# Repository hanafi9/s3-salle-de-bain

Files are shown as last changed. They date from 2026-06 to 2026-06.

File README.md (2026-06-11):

# S3 Salle de Bain

> Assistant vocal embarque ESP32-S3, prive et fonctionnant en local, dans un boitier imprime 3D dessine pour la salle de bain.






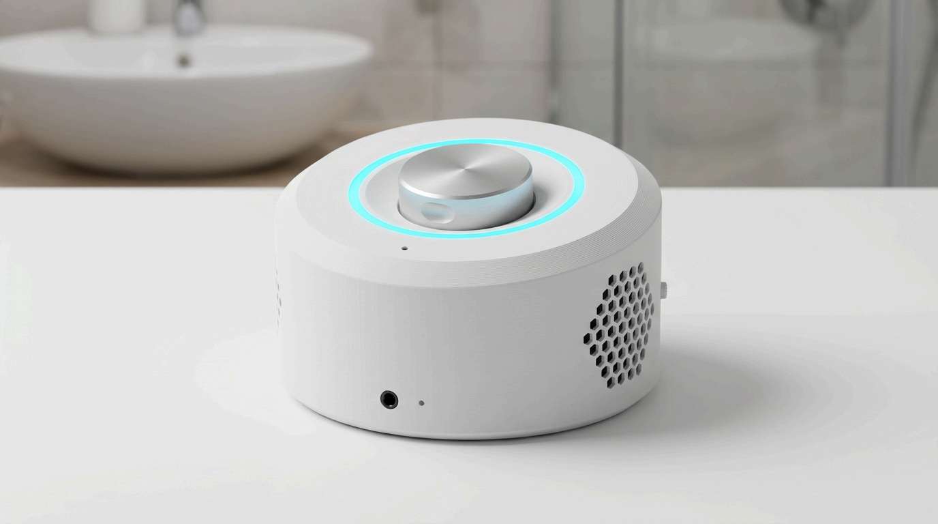
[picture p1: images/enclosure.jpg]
S3 Salle de Bain - Boitier imprime 3D


---

## Sommaire

- [Apercu](#apercu)
- [Caracteristiques](#caracteristiques)
- [Materiel](#materiel)
- [Installation](#installation)
- [Configuration](#configuration)
- [Boitier 3D](#boitier-3d)
- [Documentation](#documentation)
- [Licence](#licence)

---

## Apercu

`s3-salle-de-bain` est un assistant vocal autonome installe dans la salle de bain integrant :

- Reconnaissance vocale locale via [microWakeWord](https://github.com/kahrendt/microWakeWord) (3 modeles + stop)
- Lecteur media multi-pipeline avec mixer 2 canaux, resampler par flux et ducking automatique -20 dB
- Anneau lumineux expressif de 12 LEDs WS2812 avec 17 effets `addressable_lambda` et 14 animations contextuelles
- Interactions physiques : bouton multi-clics (1/2/3 + Morse H-A), encodeur rotatif bi-fonction (volume / teinte HSV), jack 3.5 mm avec detection, switch mute hardware
- Aucun envoi de flux audio a des services tiers par defaut : tout est traite localement

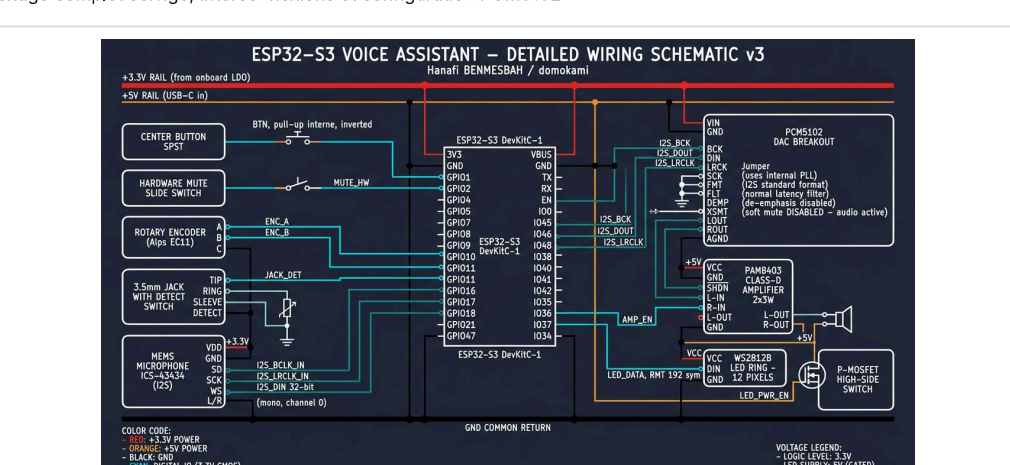
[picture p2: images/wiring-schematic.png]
Schema de cablage


---

## Caracteristiques

| | |
|---|---|
| **SoC** | ESP32-S3 DevKitC-1, 240 MHz, 16 MB Flash, PSRAM octal 80 MHz |
| **Audio** | DAC PCM5102 stereo 48 kHz / 16-bit, ampli PAM8403, 2 HP 40 mm / 4 ohms / 3 W |
| **Microphone** | MEMS I2S 32-bit mono, gain x4, VAD integre |
| **LEDs** | Anneau 12 x WS2812 GRB, refresh 15 ms, alimentation gatee via GPIO9 |
| **Reseau** | WiFi 2.4 GHz, IP statique, API ESPHome Noise Protocol, OTA chiffree |
| **Reponse audio** | 180 Hz - 18 kHz (+/- 4 dB), SPL max ~82 dB a 50 cm |
| **Boitier** | Galet cylindrique ABS blanc mat, 110 mm x 55 mm, anneau diffuseur PETG |

---

## Materiel

| Composant | Reference | Quantite |
|---|---|---|
| MCU | ESP32-S3-DevKitC-1 (N16R8) | 1 |
| DAC I2S | PCM5102 breakout | 1 |
| Amplificateur | PAM8403 Class-D | 1 |
| Microphone | INMP441 ou ICS-43434 (I2S MEMS) | 1 |
| Anneau LED | 12 x WS2812 (diametre ~50 mm) | 1 |
| Encodeur | Encodeur rotatif Alps EC11 + bouton-poussoir | 1 |
| Haut-parleurs | Pleine-bande 40 mm / 4 ohms / 3 W | 2 |
| Jack | Connecteur jack 3.5 mm chassis avec contact de detection | 1 |
| Switch mute | Interrupteur a glissiere lateral | 1 |
| MOSFET | P-MOSFET high-side (ou PNP) pour le power-gate LED | 1 |
| Inserts | Inserts filetes M3 thermofondus | 3 |

Voir [docs/Rapport Technique v3.pdf](docs/) sections 02 (schema) et 11 (BOM mecanique) pour les details.

### Brochage

| GPIO | Role |
|---|---|
| `GPIO1` | Bouton central (pull-up interne, inverted) |
| `GPIO2` | Switch mute hardware |
| `GPIO4 / 5 / 11` | Microphone MEMS I2S (LRCLK / BCLK / DIN) |
| `GPIO7 / 8 / 10` | DAC PCM5102 (LRCK / BCK / DIN) |
| `GPIO9` | Power gate LEDs (P-MOSFET) |
| `GPIO16 / 18` | Encodeur rotatif Pin A / Pin B |
| `GPIO17` | Detection jack 3.5 mm |
| `GPIO21` | Donnees WS2812 (RMT) |
| `GPIO47` | Enable amplificateur (PAM8403 SHDN) |

---

## Installation

### Prerequis

- Python 3.10+
- [ESPHome](https://esphome.io) 2025.9.3 ou superieur : `pip install esphome`
- Home Assistant 2025+ avec le composant Voice Assistant Pipeline

### Etapes

1. Cloner le repo :
   ```bash
   git clone https://github.com/hanafi09/s3-salle-de-bain.git
   cd s3-salle-de-bain
   ```

2. Copier le template de secrets :
   ```bash
   cp secrets.example.yaml secrets.yaml
   ```

3. Editer `secrets.yaml` avec tes credentials (WiFi, cle API, OTA password).
   Generer une nouvelle cle API :
   ```bash
   python -c "import secrets, base64; print(base64.b64encode(secrets.token_bytes(32)).decode())"
   ```

4. Compiler et flasher (USB-C) :
   ```bash
   esphome run s3-salle-de-bain.yaml
   ```

5. Apres le premier flash, les mises a jour suivantes peuvent se faire en OTA :
   ```bash
   esphome upload s3-salle-de-bain.yaml --device s3-salle-de-bain.local
   ```

---

## Configuration

### Niveaux de sensibilite wake word

L'entite `select.wake_word_sensitivity` expose 3 niveaux :

| Niveau | okay_nabu | hey_jarvis | hey_mycroft | FAPH* |
|---|---|---|---|---|
| Slightly sensitive | 0.85 | 0.97 | 0.99 | 0.000 (defaut) |
| Moderately sensitive | 0.69 | 0.92 | 0.95 | 0.376 - 1.502 |
| Very sensitive | 0.56 | 0.83 | 0.93 | 0.751 - 1.878 |

*FAPH = False Accepts Per Hour mesure sur le Dinner Party Corpus.

### Entites exposees a Home Assistant

| Type | Entite |
|---|---|
| `switch` | `mute`, `wake_sound` |
| `light` | `led_ring` |
| `media_player` | `external_media_player` |
| `select` | `wake_word_sensitivity` |
| `event` | `button_press` (double / triple / long / easter_egg) |
| `button` | `restart`, `factory_reset` |

### Sons embarques

16 sons via `media_player.files` (11 via substitutions YAML overridables, 5 hardcodes pour les factory reset / easter egg / cloud-auth-failed). Voir section 06 du rapport pour le tableau complet.

---

## Boitier 3D

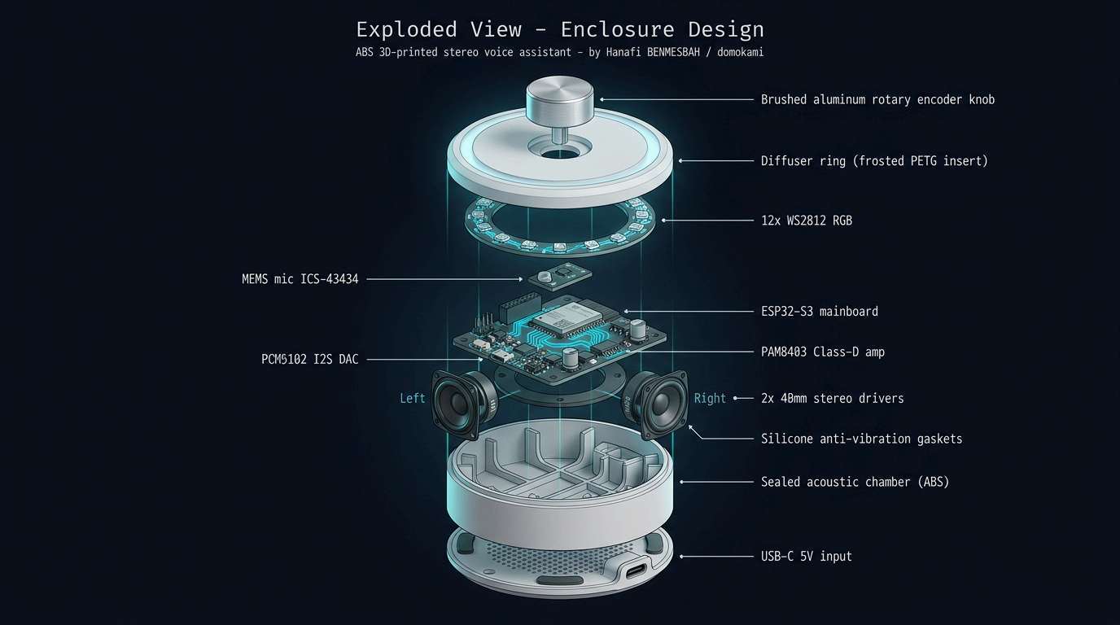
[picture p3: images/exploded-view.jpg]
Vue eclatee


Les 5 pieces du boitier sont fournies en sources parametriques OpenSCAD et apercus STL :

| Piece | Fichier source | Apercu |
|---|---|---|
| Capot superieur | [`housing_top.scad`](cad/housing_top.scad) | [`housing_top.stl`](cad/housing_top.stl) |
| Corps cylindrique | [`housing_body.scad`](cad/housing_body.scad) | [`housing_body.stl`](cad/housing_body.stl) |
| Fond | [`housing_bottom.scad`](cad/housing_bottom.scad) | [`housing_bottom.stl`](cad/housing_bottom.stl) |
| Baffle stereo | [`speaker_baffle.scad`](cad/speaker_baffle.scad) | [`speaker_baffle.stl`](cad/speaker_baffle.stl) |
| Anneau diffuseur | [`diffuser_ring.scad`](cad/diffuser_ring.scad) | [`diffuser_ring.stl`](cad/diffuser_ring.stl) |

Parametres d'impression recommandes : voir [`cad/README.txt`](cad/README.txt). En resume : ABS blanc mat, couche 0.16 mm, 4 perimetres, remplissage gyroid 25 %, ~9 h d'impression.

---

## Documentation

Le rapport technique complet (24 pages, 12 sections) est disponible :

- [PDF](docs/S3%20Salle%20de%20Bain%20-%20Rapport%20Technique%20v3.pdf) - mise en page pro, hyperliens cliquables vers les sons GitHub et fichiers CAO
- [DOCX](docs/S3%20Salle%20de%20Bain%20-%20Rapport%20Technique%20v3.docx) - editable, styles Word natifs

**Sommaire :**

1. Presentation du projet
2. Schema de cablage
3. Tableau de brochage ESP32-S3
4. Configuration des modules (PCM5102, MEMS, WS2812, alimentation)
5. Pipeline audio
6. Sons embarques (catalogue media_player.files)
7. Stack logiciel (variables globales, scripts, on_boot, timer_ringing)
8. Retour visuel (14 animations + 17 effets LED nommes)
9. Reseau et securite
10. Boitier imprime 3D
11. Vue eclatee et nomenclature (BOM + fichiers CAO)
12. Annexe YAML (extraits cles de s3-salle-de-bain.yaml)

---

## Licence

- **Firmware** (s3-salle-de-bain.yaml) et **materiel** (cad/) : [CERN-OHL-S-2.0](LICENSE)
- **Documentation** (docs/, README, images) : [CC-BY-SA-4.0](LICENSE-DOCS)

Si vous remixez ce projet, vous devez le distribuer sous les memes licences.

---

## Credits

- Auteur : **Hanafi BENMESBAH** ([@hanafi09](https://github.com/hanafi09)) / domokami
- Bibliotheques amont :
  - [ESPHome](https://esphome.io)
  - [microWakeWord](https://github.com/kahrendt/microWakeWord) (Kevin Ahrendt)
  - [Home Assistant Voice PE](https://github.com/esphome/home-assistant-voice-pe) (assets sonores)
- Inspiration boitier : tradition Dieter Rams / Braun
# s3-salle-de-bain

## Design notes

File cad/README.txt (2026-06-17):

S3 Salle de Bain - Voice Assistant Enclosure
Par Hanafi BENMESBAH / domokami
=============================================

>>> BOITIER COURANT : voir le dossier  boitier_v6/  <<<
    Style JBL (plat & large), 4 HP : 2 actifs en facade + 2 radiateurs
    passifs sur les bouts (logo DOMOKAMI) pour les basses. USB-C seul a
    l'arriere (plus de chevauchement). Carte 76,7 x 108 mm.
    Projet OrcaSlicer pret a trancher : boitier_v6/boitier_v6.3mf

    boitier_v5/ : galet integral (4 HP, radiateurs arriere) - conservee.
    boitier_v4/ : galet rectangulaire (2 HP) - conservee.

Les fichiers ci-dessous (housing_*, speaker_baffle, diffuser_ring) sont
l'ANCIEN boitier cylindrique Ø110 mm, conserve en LEGACY.

--- CONTENU (legacy, boitier cylindrique) ---

Sources parametriques (OpenSCAD) - a privilegier :
  housing_top.scad       Capot superieur avec aperture LED et bouton
  housing_body.scad      Corps cylindrique avec grilles stereo
  housing_bottom.scad    Fond avec USB-C, events, inserts M3
  speaker_baffle.scad    Plaque support haut-parleurs inclines
  diffuser_ring.scad     Anneau diffuseur PETG pour LEDs WS2812

STL simplifies (apercu / prototypage) :
  *.stl                  Meshes de volumes externes uniquement

--- RECOMPILER LES STL DEPUIS LES SOURCES ---

Installez OpenSCAD : https://openscad.org
Puis pour chaque piece :

  openscad -o housing_top.stl     housing_top.scad
  openscad -o housing_body.stl    housing_body.scad
  openscad -o housing_bottom.stl  housing_bottom.scad
  openscad -o speaker_baffle.stl  speaker_baffle.scad
  openscad -o diffuser_ring.stl   diffuser_ring.scad

--- PARAMETRES D'IMPRESSION RECOMMANDES ---

Materiau     : ABS blanc mat (PLA+ possible pour prototypage)
Couche       : 0.16 mm
Buse         : 0.4 mm
Remplissage  : 25 % gyroid
Perimeters   : 4
Top/bottom   : 5 couches
Temperature  : buse 245 C / lit 100 C (ABS)
Enceinte     : fortement recommandee pour ABS
Support      : uniquement pour les events du fond si necessaire

Piece diffuser_ring : imprimer en PETG TRANSLUCIDE, paroi 0.8 mm max
pour la diffusion de la lumiere.

--- LICENCE ---

CERN-OHL-S-2.0 / CC-BY-SA 4.0 - reutilisation libre avec attribution.

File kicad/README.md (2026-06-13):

# Projet KiCad — s3-salle-de-bain

Schéma et PCB ébauche du voice assistant ESP32-S3, **généré depuis le YAML
ESPHome** pour servir de point de départ. KiCad 8 ou supérieur recommandé.

## Fichiers livrés

| Fichier | Rôle |
|---|---|
| `s3-salle-de-bain.kicad_pro` | Projet KiCad |
| `s3-salle-de-bain.kicad_sch` | Schéma complet (23 composants, 27 nets) |
| `s3-salle-de-bain.kicad_pcb` | PCB vierge (board outline 100×80 mm) |
| `s3-salle-de-bain.net` | Netlist au format Pcbnew (compatible Eagle, etc.) |
| `sym-lib-table` | Tables symboles (utilise libs KiCad par défaut) |
| `fp-lib-table` | Tables empreintes (utilise libs KiCad par défaut) |

## Composants modélisés (23)

| Réf | Composant | Brochage YAML |
|---|---|---|
| U1 | **ESP32-S3-DevKitC-1** | GPIO1, 2, 4, 5, 7, 8, 9, 10, 11, 16, 17, 18, 21, 47 |
| U2 | **PCM5102 DAC** | BCK=GPIO8, DIN=GPIO10, LRCK=GPIO7 |
| U3 | **PAM8403 ampli class-D** | SHDN=GPIO47, sortie HP stéréo |
| U4 | **INMP441/ICS-43434 MEMS** | LRCLK=GPIO4, BCLK=GPIO5, DIN=GPIO11 |
| DS1 | **Anneau WS2812 12 LEDs** | DIN=GPIO21, alim gatée +5V_LED |
| SW1 | **Encodeur Alps EC11** | A=GPIO16, B=GPIO18, switch=GPIO1 |
| SW2 | **Switch mute SPDT** | COM=GPIO2 |
| J1 | **Jack 3.5mm** | Tip/Ring=audio, Switch=GPIO17 |
| J2 | **USB-C input** | +5V principal |
| Q1 | **P-MOSFET (AO3401)** | Gate=GPIO9, source=+5V, drain=+5V_LED |
| U5 | **AMS1117-3.3 LDO** | +5V → +3V3 |
| F1 | **Ferrite 600Ω** | Filtre rail LED |
| TVS1 | **USBLC6-2SC6** | Protection ESD USB |
| C1-C6 | Condensateurs de découplage | 10µF, 100nF, 100µF, 470µF |
| R1-R2 | Résistances | 10kΩ pullup, 330Ω série WS2812 |
| HP_L/R | Haut-parleurs 40mm 4Ω 3W | Sortie PAM8403 |

## Comment l'utiliser

### 1. Ouvrir le projet

```bash
# Ouvrir KiCad et charger le projet
kicad s3-salle-de-bain.kicad_pro
```

Ou double-cliquez sur `s3-salle-de-bain.kicad_pro` depuis l'explorateur.

### 2. Vérifier le schéma

Ouvrez le schéma (`Schematic Editor`). Vous verrez un schéma **entièrement
câblé** avec les **vrais symboles électroniques standards KiCad** :

- **Composants discrets** avec leurs symboles normalisés :
  - `Device:R` (résistances R1, R2), `Device:C` (céramiques C1-C4),
    `Device:C_Polarized` (électrolytiques C5, C6), `Device:L` (ferrite F1)
  - `Device:Q_PMOS` (MOSFET Q1 avec broches G/S/D)
  - `Device:Speaker` (haut-parleurs HP1, HP2 avec cône)
  - `Switch:SW_SPDT` (switch mute SW2)
- **Symboles d'alimentation** standards : `power:+3V3`, `power:+5V`,
  `power:GND` (avec leurs glyphes normalisés), `PWR_FLAG` sur chaque rail
- **Modules ICs** (U1 ESP32-S3, U2 PCM5102, U3 PAM8403, U4 INMP441,
  U5 AMS1117, DS1 WS2812, SW1 encodeur, J1 jack, J2 USB-C) en symboles
  rectangulaires avec broches nommées et typées (power_in sur les pins VCC/GND)
- **Câblage** : chaque broche a un stub + une étiquette de net (méthode pro pour
  schéma dense). Les nets `MIC_LRCLK`, `DAC_BCK`, `BTN_CENTER`, etc. connectent
  les broches par nom.

Les symboles standards sont **extraits exactement** de la bibliothèque KiCad 10
installée (`Device.kicad_sym`, `power.kicad_sym`, `Switch.kicad_sym`), donc
aucun avertissement de symbole non conforme.

#### Validation

Le schéma a été vérifié avec le moteur de KiCad 10 lui-même :
- `kicad-cli sch erc` : **19 avertissements mineurs** (lib `Local` non déclarée
  pour les modules custom — sans impact car symboles embarqués)
- `kicad-cli sch export pdf/svg` : rendu sans erreur
- Netlist : **24 nets, 22 composants** tous connectés

Pour régénérer après modification : `python build_kicad_v2.py` (nécessite
`kicad_std_symbols.py` dans le même dossier).

### 3. Le PCB avec **les vraies empreintes**

Le `.kicad_pcb` a été généré via l'**API pcbnew de KiCad 10** : chaque
composant utilise sa **vraie empreinte** chargée depuis les bibliothèques
KiCad installées, placée et connectée aux nets.

| Réf | Composant | Empreinte réelle |
|---|---|---|
| U1 | ESP32-S3 DevKitC-1 | **`Espressif:ESP32-S3-DevKitC`** (empreinte officielle Espressif, 2×22 pins, brochage GPIO exact) |
| U2 | PCM5102 DAC | `PinHeader_2x06` |
| U3 | PAM8403 ampli | `PinHeader_1x07` |
| U4 | INMP441 MEMS | `PinHeader_1x06` |
| U5 | AMS1117-3.3 | `Package_TO_SOT_SMD:SOT-223-3_TabPin2` |
| DS1 | Anneau WS2812 | `PinHeader_1x03` |
| SW1 | Encodeur EC11 | `Rotary_Encoder:RotaryEncoder_Alps_EC11E-Switch_Vertical_H20mm` |
| SW2 | Switch mute | `Button_Switch_THT:SW_DIP_SPSTx01_Slide` |
| J1 | Jack 3.5 mm | `Connector_Audio:Jack_3.5mm_PJ320E_Horizontal` (avec contact détection R2) |
| J2 | USB-C | `Connector_USB:USB_C_Receptacle_Amphenol_12401610E4-2A` |
| Q1 | AO3401 P-MOS | `Package_TO_SOT_SMD:SOT-23` |
| F1 | Ferrite | `Inductor_SMD:L_0805_2012Metric` |
| R1, R2 | Résistances | `Resistor_SMD:R_0603_1608Metric` |
| C1–C4 | Céramiques | `Capacitor_SMD:C_0603_1608Metric` |
| C5, C6 | Électrolytiques | `Capacitor_SMD:CP_Elec_5x5.3` |
| HP1, HP2 | Haut-parleurs | `PinHeader_1x02` |

**Validé avec `kicad-cli pcb drc` : 0 erreur.** Les 76 « éléments non
connectés » sont le **ratsnest** (liaisons à router) — c'est l'état normal
d'un PCB non encore routé. Ouvre le **PCB Editor**, tu vois les 22 empreintes
placées avec le chevelu (ratsnest) prêt à router.

Le schéma porte les mêmes empreintes (`Footprint` property), donc
`Tools → Update PCB from Schematic (F8)` fonctionne aussi si tu modifies le
schéma.

> **Note** : les modules (ESP32 DevKitC, PCM5102, PAM8403, INMP441, anneau
> WS2812) sont représentés par des **barrettes de connexion** — c'est la
> manière correcte de les intégrer (on les enfiche sur des barrettes femelles).
> La contrainte d'isolation au contour est réglée à 0,25 mm pour l'USB-C
> (connecteur de bord).

Régénérer le PCB : `"C:\Program Files\KiCad\10.0\bin\python.exe" build_pcb.py`

### 4. Routage suggéré

- **Couches** : 2 couches suffisantes (Top + Bottom)
- **Largeur des pistes** :
  - Signaux logiques : 0.25 mm
  - Alimentation 3V3 / 5V : 0.5 mm
  - Audio analogique (LOUT, ROUT vers ampli) : 0.4 mm, en étoile
  - GND : plan de masse continu sur Bottom
- **Découplage** : C1-C6 placés au plus près des broches VCC de chaque IC
- **Audio** : LOUT/ROUT du PCM5102 à PAM8403 doivent être courts et éloignés
  du signal WS2812 (rayonnement). Séparer la masse analogique (AGND) de la
  masse numérique (DGND) avec un point d'union proche du LDO.
- **WS2812** : résistance série R2 (330Ω) près de DS1, pas de l'ESP32

## Limitations connues

Ce projet est un **point de départ** généré automatiquement, pas un design
production-ready. À vérifier/compléter manuellement avant fabrication :

- [ ] Remplacer les symboles génériques par les vrais symboles KiCad
- [ ] Vérifier le brochage de chaque composant contre sa datasheet
- [ ] Ajouter une protection ESD sur les lignes I2S exposées (jack 3.5mm)
- [ ] Dimensionner la résistance pullup R1 selon la datasheet de l'encodeur
- [ ] Choisir le bon P-MOSFET (Vgs(th), Rds(on), Id selon le courant LED)
- [ ] ERC + DRC complets dans KiCad
- [ ] Simulation thermique du PAM8403 (3W RMS)

## Netlist alternatif

Si vous préférez importer dans un autre outil (Eagle, Cadstar...) :

```bash
# Le fichier .net est au format Pcbnew classique
cat s3-salle-de-bain.net
```

Il contient les 23 composants et 27 nets prêts à l'emploi.

## Licence

CERN Open Hardware Licence v2 Strongly Reciprocal (CERN-OHL-S-2.0).
Voir [../LICENSE](../LICENSE).

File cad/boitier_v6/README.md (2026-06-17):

# Boîtier v6 — style **JBL** (plat & large)

Boîtier inspiré des enceintes portables JBL (Go / Clip) : **plat, large, épuré**,
avec les **radiateurs de basse aux extrémités** (logo DOMOKAMI), comme une vraie
JBL. Corrige le chevauchement USB-C / HP de la v5. Carte **76,7 × 108 mm**.

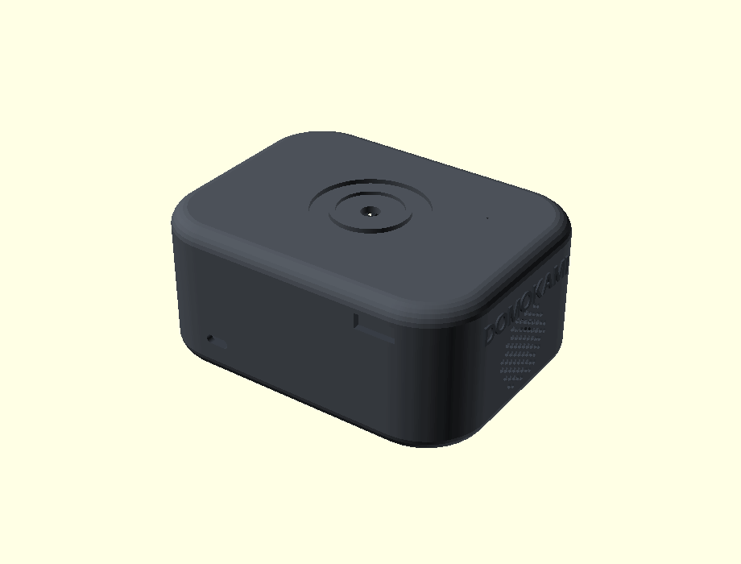
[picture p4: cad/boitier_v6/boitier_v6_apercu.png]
Aperçu

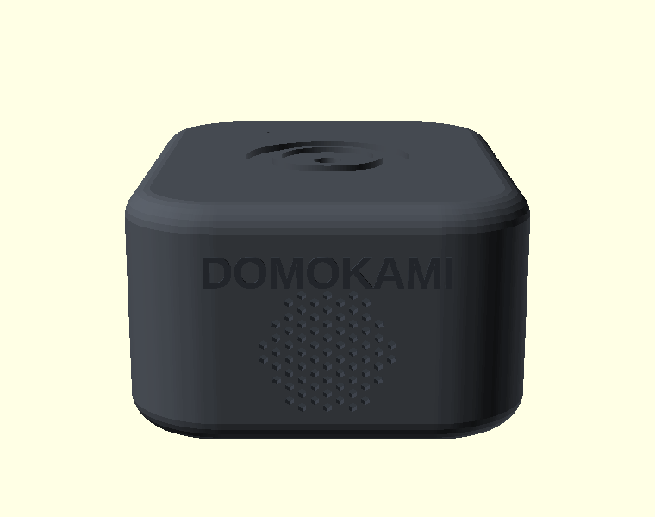
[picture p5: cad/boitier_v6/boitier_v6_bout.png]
Bout


## Pièces

| Fichier | Rôle | Matière |
|---|---|---|
| `v6_base.stl` / `.step` | Bac (façade 2 HP, bouts 2 radiateurs, USB-C, entretoises) | PA-CF |
| `v6_top.stl` / `.step` | Capot (molette, anneau LED, micro) | PA-CF |
| `v6_speaker_gasket.stl` / `.step` | 4 joints d'enceinte | TPU 95A |

Paramétrique : tout est piloté par **`params.scad`**.

## Acoustique — 4 HP, style JBL
- **2 HP plein-bande actifs en façade** (+Y), 2 grilles rondes hexagonales.
- **2 radiateurs passifs sur les 2 bouts** (±X) pour la réflexion de basse ;
  **logo DOMOKAMI en relief** au-dessus de chaque radiateur (façon logo JBL).
- **USB-C seul à l'arrière** (-Y) → **plus aucun chevauchement** avec un HP.
- **Caisson étanche** + 4 joints TPU.

## Caractéristiques
- **Encombrement** : **129 × 98 × 58 mm** (plat & large) — carte 76,7 × 108
- **Coins** R24, **arêtes** adoucies (fillet 7 mm) — look JBL Go/Clip
- **Paroi / fond** : 2,6 / 5,0 mm
- **HP** : 4 × 40 mm (2 actifs façade + 2 radiateurs passifs bouts), z = 24 mm
- **Encodeur** EC11 sur le capot (douille M7) ; **anneau LED** Ø44/30
- **Micro** pinhole au-dessus de l'INMP441 ; **fixation PCB** 4 × M3 (MK1–MK4)
- **Montage HP** par l'intérieur (façade nette, sans cercle)
- **Fermeture** lèvre press-fit (sans vis) + encoche de démontage

## Impression (RatRig V-Core 3 400, buse 0,4)
PA-CF, couche 0,2 mm, 4 périmètres, 5 dessus/dessous, gyroïde 25 %, **sans
support**, buse 290 °C / plateau 100 °C. Projet OrcaSlicer : `boitier_v6.3mf`.
Joints HP en **TPU 95A**. v4 et v5 conservées dans `cad/`.

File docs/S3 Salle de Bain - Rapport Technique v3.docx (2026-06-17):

DOMOKAMI | Rapport Technique · Juin 2026

ASSISTANT VOCAL EMBARQUE · PROJET v3

S3 Salle de Bain.

Dispositif autonome installe dans la salle de bain integrant reconnaissance vocale locale (microWakeWord), lecteur media multi-pipeline et anneau lumineux expressif de 12 WS2812. Base sur ESP32-S3 DevKitC-1, firmware declaratif YAML ESPHome.

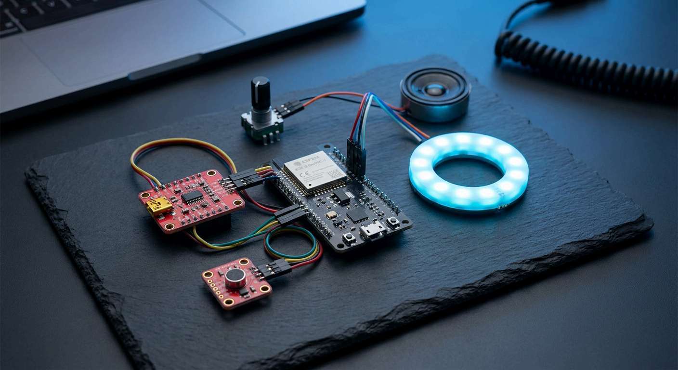
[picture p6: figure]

SOC ESP32-S3 240 MHz | MEMOIRE 16 MB + 8 MB Flash + PSRAM | AUDIO PCM5102 I2S 48 kHz / 16-bit | LEDS 12 x WS2812B RGB | RESEAU Wi-Fi 802.11 b/g/n

AUTEUR Hanafi Benmesbah | DEPOT SOURCE github.com/hanafi09/s3-salle-de-bain | CIBLE Home Assistant 2025+

SOMMAIRE

Table des matieres

01 | Presentation du projet Architecture materielle, logicielle et trois couches de feedback | 03
02 | Schema de cablage Brochage complet corrige et configuration PCM5102 | 04
03 | Tableau de brochage Description detaillee des entrees / sorties ESP32-S3 | 05
04 | Configuration des modules PCM5102, microphone MEMS, anneau WS2812, alimentation | 06
05 | Pipeline audio Chaine de traitement complete, format des flux et mixage | 08
06 | Sons embarques Catalogue des fichiers media_player.files | 09
07 | Stack logiciel ESPHome, wake words, entites, variables globales, scripts | 10
08 | Retour visuel Anneau WS2812, 14 animations et mapping des partitions | 12
09 | Reseau et securite Connectivite, services exposes et mecanismes de protection | 14
10 | Boitier imprime 3D Boitier plat style JBL, 4 HP, radiateurs de basse aux extremites (logo DOMOKAMI) | 15
11 | Vue eclatee et nomenclature Architecture interne, configuration acoustique, fichiers CAO | 16
12 | Annexe YAML Extraits cles de s3-salle-de-bain.yaml (ESPHome 2025.9.3+) | 18

RESUME

Le module s3-salle-de-bain est un assistant vocal prive concu pour fonctionner dans un environnement humide. Il s’appuie sur l’ecosysteme Home Assistant Voice Preview Edition, et remplace entierement les assistants proprietaires par une solution locale, sans envoi de flux audio a des services tiers par defaut. Le wake word est detecte directement sur le microcontroleur grace au moteur microWakeWord. Le firmware est entierement declaratif en YAML, ESPHome.

§ 01

Presentation du projet

Architecture materielle et logicielle, trois couches de feedback

Dispositif autonome installe dans la salle de bain integrant reconnaissance vocale locale (microWakeWord), lecteur media multi-pipeline avec mixer et resampler, anneau lumineux expressif de 12 WS2812 avec 14 animations contextuelles, et interactions physiques (bouton multi-clics, encodeur rotatif bi-fonction, jack 3.5 mm avec detection).

Le systeme integre trois couches de feedback utilisateur : visuel (anneau LED), sonore (effets de confirmation, sons d'erreur, timer) et haptique indirect (retour du clic et du cran de l'encodeur). L'ensemble est pilote par une machine a etats centrale qui route les animations en fonction du contexte : initialisation, connexion WiFi/API, phase du pipeline vocal, timer actif, mute, changement de volume ou de couleur.

Detection locale microWakeWord execute 3 modeles en parallele avec seuils de sensibilite ajustables. Gain x4, VAD integre, stop-word actif pendant TTS pour limiter les declenchements parasites. | | Audio haute qualite DAC PCM5102 stereo 48 kHz via I2S. Pipeline virtuel avec mixer 2 canaux (announcement + media), resampler par flux, ducking -20 dB automatique. | | Feedback visuel riche Anneau 12 WS2812 remappe en 2 partitions, 14 animations codees en lambdas adressables, teinte controlee a l'encodeur.

Interactions physiques Bouton central multi-clics (1/2/3), appui long 1 s, 10 s pour reset prompt, 22 s pour factory reset confirme, et easter-egg Morse H-A. | | Connectivite WiFi 2.4 GHz IP statique 192.168.1.197, API ESPHome chiffree Noise Protocol, OTA port 3232, fallback AP Voice-S3-Fallback, captive portal. | | Securite & robustesse Cle API chiffree, mute hardware prioritaire sur le logiciel, factory reset a 22 s de pression, reboot watchdog 15 min, firmware OTA protege par mot de passe.

§ 02

Schema de cablage

Brochage complet corrige, interconnexions et configuration PCM5102

Le brochage ci-dessous correspond exactement a la configuration YAML s3-salle-de-bain.yaml. Le DAC PCM5102 utilise trois broches I2S (BCK, DIN, LRCK) plus cinq broches de configuration fixes (SCK, FMT, FLT, DEMP, XSMT) qui ne se cablent pas au microcontroleur mais directement a GND ou 3.3 V. Aucun bus I2C n'est requis avec ce DAC. Une ligne de masse commune partage MCU, DAC, micro et amplificateur.


Fig. 1 - Schema d'interconnexion ESP32-S3 / PCM5102 / peripheriques (v3).

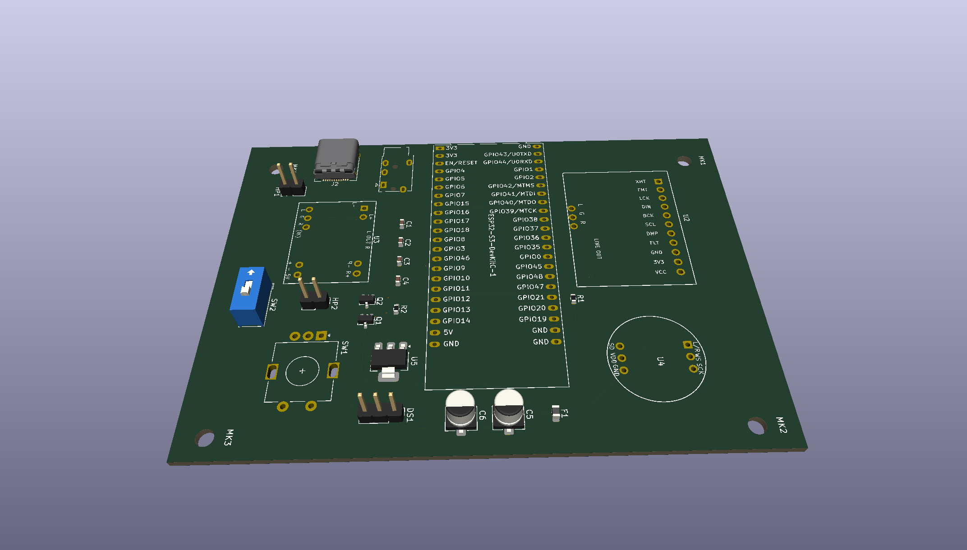
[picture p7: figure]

Fig. 2 - Implantation du PCB (rendu KiCad) : placement des composants, footprints reels et trous de fixation M3.

Corrections depuis la v1 du schema. GPIO9 requalifie en power gate LED (via power_supply) - GPIO10 identifie en DOUT (sortie I2S vers DAC), pas entree - GPIO47 ajoute comme enable de l'amplificateur (etait absent) - GPIO11 explicitement mis en 32-bit PDM off - Suppression du bus I2C (non utilise avec PCM5102) - XSMT du PCM5102 tire a 3.3 V (soft mute desactive). Budget courant pic estime : 900 mA (LEDs pleine blancheur).

§ 03

Tableau de brochage ESP32-S3

Description detaillee des entrees / sorties

Les broches sont reparties en cinq groupes fonctionnels : entrees physiques (bouton, encodeur, jack, switch mute), microphone MEMS sur bus I2S dedie, DAC audio sur second bus I2S, anneau LED RMT et gating d'alimentation. Toutes les broches sont declarees explicitement dans le YAML.

GPIO | ROLE | DESCRIPTION
GPIO1 | ENTREE - Bouton central | Bouton poussoir SPST (pull-up interne, signal inverse). Pull-up interne actif, option inverted: true pour que 'enfonce' = ON. Simple/double/triple clic, appui long >=1 s, Morse H-A, factory reset 22 s.
GPIO2 | ENTREE - Switch mute materiel | Interrupteur lateral physique (coupe-micro hardware). Commutateur a glissiere entre GPIO2 et GND. Priorite absolue sur le mute logiciel : tant que ferme, microphone.unmute est interdit. Sons mute_switch_on / off.
GPIO4 / 5 / 11 | ENTREE - Bus I2S micro (i2s_in) | Microphone MEMS numerique I2S 32-bit mono. GPIO4 = LRCLK (Word Select), GPIO5 = BCLK, GPIO11 = DIN. Alim +3.3 V, GND commun. pdm: false, bits_per_sample: 32bit, canal 0 mono.
GPIO16 / 18 | ENTREE - Encodeur rotatif | Encodeur quadrature mecanique (bi-fonction). Pin A sur GPIO16, Pin B sur GPIO18, commune a GND. Resolution 2 detentes par cran. Relache : volume media (0.05 increment, bornes 0.4 - 0.85). Enfonce : teinte HSV +/- 10 deg.
GPIO17 | ENTREE - Detection jack 3.5 mm | Contact de commutation du connecteur jack. Cable entre GPIO17 et GND. Filtres delayed_on / delayed_off 200 ms anti-rebond. Anim 'ripple' Jack Plugged / Unplugged + son de confirmation. Variable jack_plugged_recently bloque 800 ms.
GPIO7 / 8 / 10 | SORTIE - Bus I2S DAC (i2s_output) | Transmission audio stereo vers le PCM5102. GPIO7 = LRCK, GPIO8 = BCK, GPIO10 = DIN du DAC. PCM5102 en mode esclave, PLL interne (SCK a GND). Format I2S standard, FLT normal latency, DEMP off, XSMT tire au 3.3 V.
GPIO9 | SORTIE - Power gate LEDs | Controle d'alimentation de l'anneau WS2812. Commande P-MOSFET high-side qui coupe le +5 V du ruban WS2812 quand inactif. power_supply: led_power active automatiquement le rail a la demande. Reduit la consommation au repos.
GPIO21 | SORTIE - Donnees WS2812 | Ligne de donnees RMT vers l'anneau 12 LEDs. Signal serie WS2812 genere par RMT (rmt_symbols: 192, chipset WS2812, rgb_order GRB, max_refresh_rate 15 ms). Partitions [7..11] + [0..6] pour aligner l'indice 0 sur la LED a 12 h.
GPIO47 | SORTIE - Enable amplificateur | Activation de l'amplificateur audio de sortie. Broche SHDN / EN de l'ampli Class-D. restore_mode: ALWAYS_OFF, mis a ON 1 s apres boot par script, evite les pops pendant l'init du DAC. Ampli alimente en +5 V.

§ 04

Configuration des modules

PCM5102, microphone MEMS, anneau WS2812, alimentation

PCM5102 DAC

Le DAC PCM5102 utilise trois broches I2S (BCK, DIN, LRCK) plus cinq broches de configuration fixes (SCK, FMT, FLT, DEMP, XSMT) qui ne se cablent pas au microcontroleur mais directement a GND ou 3.3 V. Aucun bus I2C n'est requis avec ce DAC.

PIN DAC | CONNEXION | ROLE
VIN | 3.3 V | Alimentation logique
GND | GND | Masse
BCK | GPIO8 | Bit Clock I2S
DIN | GPIO10 | Donnees audio (data in DAC)
LRCK | GPIO7 | Word Select (L/R)
SCK | GND | Master clock (PLL interne)
FMT | GND | Format I2S standard
FLT | GND | Filtre normal latency
DEMP | GND | De-emphasis desactive
XSMT | 3.3 V | Soft mute off (active)

ALIMENTATION - Entree principale 5 V USB-C sur le DevKitC-1 - Regulateur LDO 3.3 V integre pour MCU, DAC et micro - Rail 5 V partage pour les 12 WS2812 (gate GPIO9) - Ampli audio active 1 s apres boot (GPIO47) - Budget courant pic estime : 900 mA (LEDs pleine blancheur) | | CORRECTIONS DEPUIS LA V1 DU SCHEMA - GPIO10 identifie en DOUT (sortie I2S vers DAC), pas entree - GPIO11 explicitement mis en 32-bit PDM off - GPIO47 ajoute comme enable de l'ampli (etait absent) - GPIO9 requalifie en power gate LED (via power_supply) - Suppression du bus I2C (non utilise avec PCM5102) - Rails d'alimentation +3.3 V / GND explicitement traces - GND commun partage entre MCU, DAC, micro et ampli - XSMT du PCM5102 tire au +3.3 V (soft mute desactive)

§ 05

Pipeline audio

Chaine de traitement complete, format des flux et mixage

L'architecture audio repose sur deux bus I2S physiquement distincts. Le premier (i2s_in) transporte les donnees 32-bit du micro MEMS vers le SoC et alimente la detection de wake word ainsi que la capture pour le pipeline Home Assistant. Le second (i2s_output) transmet un flux stereo 16-bit 48 kHz au DAC PCM5102. Les flux applicatifs (annonces, media) sont uniformises en amont par deux etages resampler, puis combines par un mixer logiciel avant d’etre serialises sur le bus I2S de sortie.

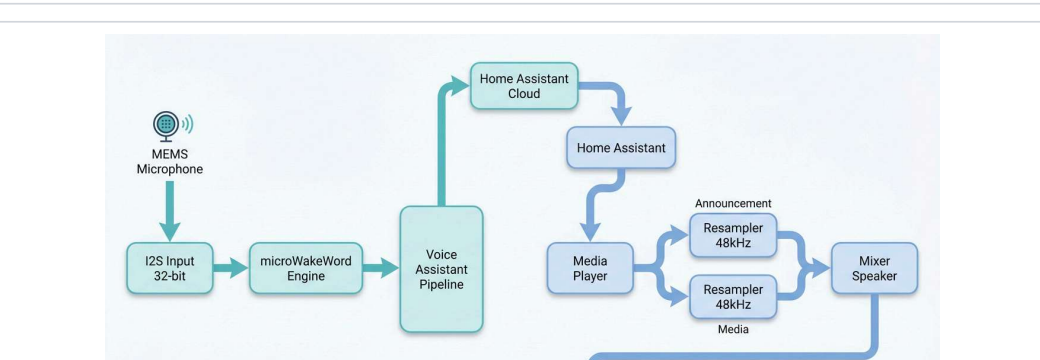
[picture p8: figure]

Fig. 3 - Pipeline audio bidirectionnel ESPHome / Home Assistant.

ENTREE / capture vocale Microphone MEMS. I2S 32-bit mono canal 0, bus i2s_in microWakeWord. 3 modeles + stop, gain x4, VAD actif Voice Assistant. Stream audio vers HA, noise_suppression 0, auto_gain 0 dBFS Home Assistant Pipeline. STT -> Intent resolution -> TTS stream | | SORTIE / lecture Media Player (virtuel). Volume 40 %-85 %, increment 5 %, FLAC Resampler x2 flux. announcement + media vers 48 kHz / 16-bit Speaker mixer 2 canaux. Ducking -20 dB pendant annonces, transition 0 s / 1 s I2S -> PCM5102 -> Jack 3.5. Stereo 48 kHz, buffer 100 ms, timeout never

FORMAT ANNOUNCEMENTS Codec FLAC Canaux 1 (mono) Sample rate 48 000 Hz Bits 16 | | FORMAT MEDIA Codec FLAC Canaux 2 (stereo) Sample rate 48 000 Hz Bits 16 | | DUCKING / REPEAT Ducking annonces -20 dB Transition off 1 s Repeat one actif pdt timer Delay playlist 500 ms

§ 06

Sons embarques

Catalogue des fichiers media_player.files

Tous les retours sonores sont declares dans media_player.files et telecharges depuis le depot officiel esphome/home-assistant-voice-pe. Les 11 sons standards passent par les substitutions YAML (overridables par l'utilisateur), les 5 sons specifiques au firmware (factory reset, easter egg, cloud expired) pointent directement vers GitHub.

ID FICHIER | FORMAT | SOURCE | ASSET GITHUB
center_button_press_sound | FLAC | subs | center_button_press.flac (https://github.com/esphome/home-assistant-voice-pe/raw/dev/sounds/center_button_press.flac)
center_button_double_press_sound | FLAC | subs | center_button_double_press.flac (https://github.com/esphome/home-assistant-voice-pe/raw/dev/sounds/center_button_double_press.flac)
center_button_triple_press_sound | FLAC | subs | center_button_triple_press.flac (https://github.com/esphome/home-assistant-voice-pe/raw/dev/sounds/center_button_triple_press.flac)
center_button_long_press_sound | FLAC | subs | center_button_long_press.flac (https://github.com/esphome/home-assistant-voice-pe/raw/dev/sounds/center_button_long_press.flac)
jack_connected_sound | FLAC | subs | jack_connected.flac (https://github.com/esphome/home-assistant-voice-pe/raw/dev/sounds/jack_connected.flac)
jack_disconnected_sound | FLAC | subs | jack_disconnected.flac (https://github.com/esphome/home-assistant-voice-pe/raw/dev/sounds/jack_disconnected.flac)
mute_switch_on_sound | FLAC | subs | mute_switch_on.flac (https://github.com/esphome/home-assistant-voice-pe/raw/dev/sounds/mute_switch_on.flac)
mute_switch_off_sound | FLAC | subs | mute_switch_off.flac (https://github.com/esphome/home-assistant-voice-pe/raw/dev/sounds/mute_switch_off.flac)
wake_word_triggered_sound | FLAC | subs | wake_word_triggered.flac (https://github.com/esphome/home-assistant-voice-pe/raw/dev/sounds/wake_word_triggered.flac)
timer_finished_sound | FLAC | subs | timer_finished.flac (https://github.com/esphome/home-assistant-voice-pe/raw/dev/sounds/timer_finished.flac)
factory_reset_initiated_sound | MP3 | URL direct | factory_reset_initiated.mp3 (https://github.com/esphome/home-assistant-voice-pe/raw/dev/sounds/factory_reset_initiated.mp3)
factory_reset_cancelled_sound | MP3 | URL direct | factory_reset_cancelled.mp3 (https://github.com/esphome/home-assistant-voice-pe/raw/dev/sounds/factory_reset_cancelled.mp3)
factory_reset_confirmed_sound | MP3 | URL direct | factory_reset_confirmed.mp3 (https://github.com/esphome/home-assistant-voice-pe/raw/dev/sounds/factory_reset_confirmed.mp3)
easter_egg_tick_sound | MP3 | URL direct | easter_egg_tick.mp3 (https://github.com/esphome/home-assistant-voice-pe/raw/dev/sounds/easter_egg_tick.mp3)
easter_egg_tada_sound | MP3 | URL direct | easter_egg_tada.mp3 (https://github.com/esphome/home-assistant-voice-pe/raw/dev/sounds/easter_egg_tada.mp3)
error_cloud_expired | MP3 | URL direct | error_cloud_expired.mp3 (https://github.com/esphome/home-assistant-voice-pe/raw/dev/sounds/error_cloud_expired.mp3)

§ 07

Stack logiciel

ESPHome, wake words, entites, variables globales, scripts

FIRMWARE ESPHome 2025.9.3+ ESP-IDF recommande PSRAM octal 80 MHz Cache data 64 KB Cache instruction 32 KB mbedTLS TLS 1.3 | | AUDIO i2s_audio (x2 bus) Speaker mixer 2 canaux Resampler x2 flux Media player virtuel Ducking automatique Buffer 100 ms | | VOICE AI microWakeWord local VAD integre Voice Assistant API Wake word selector 3 niveaux Stop word actif pendant timer Noise suppression 0

WAKE WORDS & SEUILS DE DECLENCHEMENT

| Modele principal (kahrendt v20241226.3), cutoffs 0.56 / 0.69 / 0.85
| Modele alternatif v2, cutoffs 0.83 / 0.92 / 0.97
| Modele alternatif v2, cutoffs 0.93 / 0.95 / 0.99
| Mot d'interruption actif pendant TTS et timer

NIVEAUX DE SENSIBILITE (entite select)

NIVEAU | okay_nabu | hey_jarvis | hey_mycroft | NOTES
Slightly sensitive | 0.85 (217) | 0.97 (247) | 0.99 (253) | 0.000 FAPH (defaut)
Moderately sensitive | 0.69 (176) | 0.92 (235) | 0.95 (242) | 0.376 - 1.502 FAPH
Very sensitive | 0.56 (143) | 0.83 (212) | 0.93 (237) | 0.751 - 1.878 FAPH

Probability cutoff (float) / quantized uint8 entre parentheses. FAPH = False Accepts per Hour mesure sur le Dinner Party Corpus.

ENTITES EXPOSEES A HOME ASSISTANT

SWITCH | mute wake_sound
LIGHT | led_ring
MEDIA_PLAYER | external_media_player
SELECT | wake_word_sensitivity
EVENT | button_press
BUTTON | restart factory_reset

VARIABLES GLOBALES / state machine

VARIABLE | TYPE / ROLE
voice_assistant_phase | int - phase courante (1..11)
init_in_progress | bool - vrai jusqu'a connexion HA
improv_ble_in_progress | bool - provisioning BLE actif
dial_touched | bool - encodeur recemment tourne
color_changed | bool - teinte en cours de modification
jack_plugged_recently | bool - anim ripple en cours
jack_unplugged_recently | bool - anim ripple en cours
first_active_timer | Timer - timer courant
is_timer_active | bool - au moins un timer actif
factory_reset_requested | bool - reset en attente de release
global_led_animation_index | int - rotation anneau

SEQUENCE DE DEMARRAGE / on_boot

ETAPE | ROLE
Priorite 375 | Hook execute apres init reseau et services
script.execute: control_leds | Demarre l'animation Twinkle (init_in_progress = true)
delay: 1 s | Stabilisation du DAC (evite les pops audio)
switch.turn_on: internal_speaker_amp | Active l'ampli (GPIO47 - PAM8403 SHDN)
delay: 10 min | Timeout absolu sur la connexion HA / Voice Assistant
if (init_in_progress) | Si toujours en init : on bascule a false et on relance control_leds

SCRIPTS PRINCIPAUX

SCRIPT | ROLE
control_leds | Router central, priorite par contexte
control_volume | Volume up/down + LED feedback
control_hue | Cycle HSV +/- 10 deg
ring_timer | Active repeat one + son timer
enable_repeat_one | Mode REPEAT_ONE sur media_player
disable_repeat | Retour REPEAT_OFF
play_sound | Lecture son avec priorite optionnelle
fetch_first_active_timer | Selection du timer le plus urgent
check_if_timers_active | Booleen global is_timer_active
activate_stop_word_once | Stop-word pendant TTS long

LOGIQUE INTERNE / switch timer_ringing

Switch interne (non expose a HA) qui orchestre la sonnerie de timer. Sa transition pilote en cascade le ducking media, l'activation du wake word stop, le repeat_one, et l'animation visuelle.

TRIGGER | ACTION
on_turn_on | Apply ducking -20 dB (duration 0 s) sur media_mixing_input
| micro_wake_word.enable_model: stop
| script.execute: ring_timer (active REPEAT_ONE + son)
| script.execute: control_leds (animation Timer Ring)
Timeout | Apres 15 min : switch.turn_off automatique (securite)
on_turn_off | micro_wake_word.disable_model: stop
| script.execute: disable_repeat (REPEAT_OFF)
| Stop announcement en cours (media_player.stop si is_announcing)
| Apply ducking 0 dB (transition 1 s) - retour volume normal
| script.execute: control_leds (retour etat contextuel)

§ 08

Retour visuel

Anneau WS2812, 14 animations et mapping des partitions

L'anneau physique (GPIO21, chipset WS2812 GRB, refresh 15 ms) est decoupe en deux partitions virtuelles. La premiere (voice_assistant_leds) est interne et pilotee par la machine a etats. La seconde (led_ring) est exposee a Home Assistant pour un controle utilisateur direct (couleur, luminosite, on/off). Les deux sont mappees sur les memes 12 LEDs physiques avec le decoupage [7..11] puis [0..6] pour aligner l'indice 0 sur la LED situee a 12 h (top). Chaque etat de la machine appelle une lambda adressable avec un update_interval adapte (10 ms pour les pulses, 50 ms pour les spins, 1 s pour les indicateurs lents). La luminosite est interpolee depuis la valeur utilisateur avec un minimum de 20 % pour garantir la visibilite.

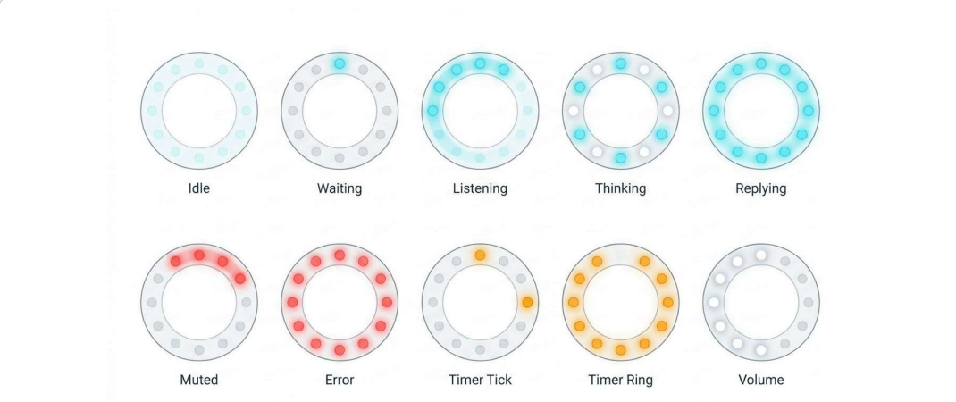
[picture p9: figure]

Fig. 4 - Dix etats de l'anneau LED, du repos a la sonnerie de minuterie.

14 ANIMATIONS CONTEXTUELLES

ANIMATION | DESCRIPTION
Idle | En attente du wake word, anneau eteint ou couleur utilisateur
Waiting | Spin horaire lent (100 ms) apres wake word
Listening | Spin horaire rapide (50 ms) pendant STT/VAD
Thinking | Pulse deux LEDs opposees (10 ms), 10 paliers
Replying | Spin anti-horaire pendant TTS
Muted | LEDs rouges aux positions micros et HP
Error | Pulse rouge complet, sortie apres 1 s
Timer Tick | Remplissage proportionnel au temps restant
Timer Ring | Pulse complet a la sonnerie
Jack Plug / Unplug | Ripple double-sens, 40 ms
Volume Display | Barre proportionnelle au volume media
Rainbow | Easter egg morse H-A (.... ._)
Factory Reset | Remplissage rouge progressif, 1 s par LED
No HA Connection | Twinkle rouge pendant perte API/WiFi

EFFETS LED NOMMES / voice_assistant_leds[effects]

Les 14 animations contextuelles s'appuient sur 17 effets addressable_lambda declares dans la partition voice_assistant_leds. Chaque effet a son propre update_interval et utilise la teinte courante de led_ring comme couleur de base.

NOM EFFET (YAML) | TYPE | INTERVALLE
Waiting for Command | lambda | 100 ms
Listening For Command | lambda | 50 ms
Thinking | lambda | 10 ms
Replying | lambda | 50 ms
Muted or Silent | lambda | 16 ms
Voice kit startup failed | lambda statique | -
Volume Display | lambda | 50 ms
Center Button Touched | lambda | 16 ms
Twinkle | twinkle | probability 50 %
Error | lambda pulse | 10 ms
Timer Ring | lambda pulse | 10 ms
Timer Tick | lambda | 100 ms
Rainbow | rainbow | width 12
Tick | lambda (Morse) | 333 ms
Factory Reset Coming Up | lambda progressif | 1 s par LED
Jack Plugged | lambda ripple | 40 ms
Jack Unplugged | lambda ripple | 40 ms

MACHINE A ETATS - BOUTON CENTRAL

EVENEMENT | DUREE | DESCRIPTION
Simple clic | < 1 s | Arret en cascade : timer > announcement > pipeline vocal > media. Demarre le VA si rien n'est actif et si non mute.
Double clic | ~ 1 s x2 | Evenement expose button_press.double_press pour automations HA, son de confirmation joue.
Triple clic | ~ 1 s x3 | Evenement triple_press, son dedie, non mappe par defaut dans le firmware.
Appui long | >= 1 s | Evenement long_press, extinction de l'anneau LED, son de confirmation.
Avertissement reset | 10 s | Animation rouge progressive + son factory_reset_initiated. Annulable au relachement.
Factory reset confirme | 22 s | Son factory_reset_confirmed, LED rouge fixe, efface la config au relachement.
Easter egg | Morse H-A | Sequence .... / ._ en moins de 2 s par pulse. Anime Rainbow + son tada.
LED activation | on_press | Anneau allume en couleur utilisateur au simple contact, script control_leds_center_button_touched.
Retour idle | on_release | Relance control_leds pour retrouver l'animation contextuelle courante.

§ 09

Reseau et securite

Connectivite, services exposes et mecanismes de protection

CONFIGURATION RESEAU SSID domkam (2.4 GHz) IP statique 192.168.1.197 Gateway 192.168.1.254 Masque 255.255.255.0 DNS 1 / DNS 2 192.168.1.254 / 8.8.8.8 Fast connect active Power save NONE (latence min) AP fallback Voice-S3-Fallback Captive portal active mDNS active | | SERVICES EXPOSES PORT / NOM DETAIL 6053 API ESPHome Noise Protocol chiffre, reboot watchdog 15 min 80 Web server v2 include_internal true, OTA desactivee sur ce port 3232 OTA ESPHome Protege par mot de passe mDNS Auto-decouverte Resolution locale s3-salle-de-bain.local LOG Debug stream Niveau DEBUG, log i2s_audio DEBUG

Chiffrement API Cle pre-partagee Noise Protocol 32 octets, sessions ephemeres, pas d'exposition des donnees vocales. | | OTA securise Mot de passe dedie pour le port 3232, desactive sur le serveur web v2 pour eviter toute surface inutile. | | Resilience Si perte API ou WiFi, anim rouge twinkle. AP fallback demarre automatiquement pour reconfig Improv BLE.

§ 10

Boitier imprime 3D

Boitier plat style JBL, 4 HP, radiateurs de basse aux extremites (logo DOMOKAMI)

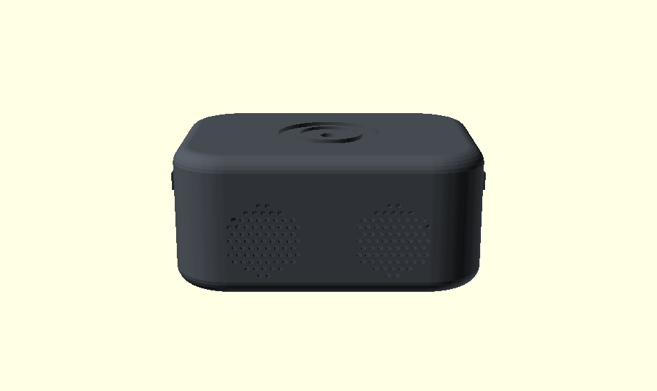
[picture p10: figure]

Fig. 5 - Boitier v6, style JBL (rendu CAO) : facade 2 HP, radiateurs de basse + logo DOMOKAMI aux bouts.

PHILOSOPHIE DU DESIGN

Le boitier adopte un format plat et large inspire des enceintes portables JBL (Go / Clip) : 129 x 98 mm pour seulement 58 mm de hauteur, aux aretes adoucies (fillet 7 mm). Le capot et le bac se ferment par une levre peripherique en press-fit : aucune vis visible, seule une encoche laterale permet le demontage. L'inspiration puise dans la tradition Dieter Rams / Braun : minimalisme, fonction evidente, absence totale d'ornement superflu.

Imprime en PA-CF, le boitier est un caisson acoustique ETANCHE (sans events). Il loge QUATRE haut-parleurs de 40 mm : deux pleine-bande actifs en FACADE (2 grilles rondes) et deux RADIATEURS PASSIFS sur les deux BOUTS (gauche/droite) qui renforcent les basses par la pression interne (aucun cablage, electronique inchangee). Chaque bout porte le logo DOMOKAMI en relief, a la maniere du logo JBL sur la membrane de basse. L'USB-C est seul a l'arriere : plus aucun chevauchement avec un haut-parleur.

Ergonomie & basses. La molette centrale (encodeur EC11 a montage panneau + anneau LED) tombe sous le doigt ; le volume interne et les radiateurs passifs des extremites donnent une assise de basses inhabituelle pour ce format compact. Prevoir les 4 joints TPU (etancheite) pour en profiter pleinement.

DIMENSIONS Encombrement 129 x 98 x 58 mm Carte 76,7 x 108 mm Style plat & large (JBL) Paroi / fond 2,6 / 5,0 mm Coins R24, bords R7 | | IMPRESSION 3D Matiere PA-CF Remplissage gyroid 25 % Parois 4 perimetres Dessus / dessous 5 couches Buse / plateau 290 / 100 C | | FINITIONS HP 4 x 40 mm (2+2) Basses 2 radiateurs passifs Caisson etanche (sans events) Joints 4 x TPU 95A Assemblage aucune vis visible

§ 11

Vue eclatee et nomenclature

Architecture interne, configuration acoustique, fichiers CAO

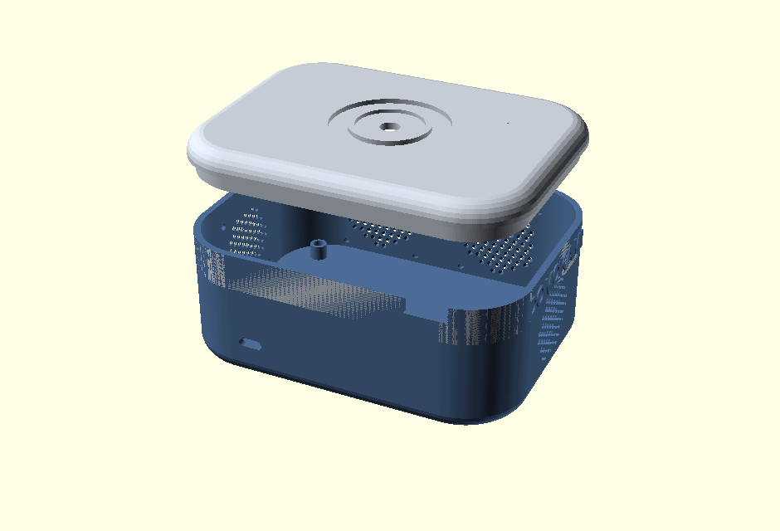
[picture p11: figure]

Fig. 6 - Vue eclatee du boitier v6 : capot a molette + bac (2 HP facade, 2 radiateurs aux bouts).

ARCHITECTURE INTERNE 1. Capot plat PA-CF, molette centrale, gorge anneau LED, levre press-fit 2. Encodeur EC11 Montage panneau (douille M7), cable aux connecteurs SW1/DS1 3. Anneau LED WS2812 sous capot, gorge diffusante (O44/30 mm) 4. Microphone MEMS Pinhole conique 0.8 mm, place au-dessus du module INMP441 5. PCB porteur ESP32-S3, PCM5102, ampli PAM8403 - carte 76,7 x 108 mm 6. HP actifs (x2) 40 mm plein-bande, facade +Y, 2 grilles rondes 7. Radiateurs (x2) 40 mm passifs, sur les 2 bouts +-X, logo DOMOKAMI relief 8. Bac etanche PA-CF, entretoises MK1-MK4, USB-C seul a l'arriere | | CONFIGURATION ACOUSTIQUE 4 haut-parleurs 40 mm 2 actifs facade + 2 radiateurs bouts Radiateurs sur les bouts reflexion de basse (style JBL) Caisson etanche sans events (essentiel basses) 4 joints d'enceinte TPU etancheite / compression USB-C isole a l'arriere plus de chevauchement avec un HP Coque PA-CF plate rigide, limite les resonances Reponse visee ~80 Hz - 18 kHz (basses renforcees) SPL max utile ~84 dB a 50 cm

NOMENCLATURE MATERIAUX / BOM mecanique

PIECE | MATERIAU | QTE | NOTES
Capot (v6_top) | PA-CF | 1 | Impression 3D, parois 4, gyroid 25 %
Bac (v6_base) | PA-CF | 1 | Plat JBL, 4 HP, USB-C, entretoises
Joints d'enceinte | TPU 95A | 4 | v6_speaker_gasket, compression
Bouton central | Alu 6061 brosse anodise | 1 | Sur encodeur EC11 (douille M7)
Anneau LED | WS2812 (12 LED) | 1 | Monte sous capot, gorge diffusante
HP actifs | 40 mm / 4 ohms / 3 W | 2 | Pleine-bande, facade
Radiateurs passifs | 40 mm passifs | 2 | Sur les bouts, logo DOMOKAMI
Vis M3 / M2.5 | Inox | 20 | PCB (4) + HP (16)
Pieds silicone | Shore A 30 | 4 | Anti-derapant, sous le bac

TELECHARGEMENT DES FICHIERS CAO

Les trois pieces du boitier sont fournies en sources parametriques OpenSCAD (.scad), en maillages STL, en solides STEP (reference CAO / fabricant) et en projet OrcaSlicer .3mf pret a trancher (reglages PA-CF). Les sources .scad sont la verite du design (tout est pilote par params.scad) ; le .3mf permet d'imprimer directement sur RatRig V-Core 3 400.

PIECE | DESCRIPTION | STL | STEP
v6_base | Bac plat JBL : 4 HP, USB-C, entretoises | v6_base.stl | v6_base.step
v6_top | Capot : molette, anneau LED, micro | v6_top.stl | v6_top.step
v6_speaker_gasket | Joints d'enceinte x4 (TPU) | v6_speaker_gasket.stl | v6_speaker_gasket.step

README.md - parametres d'impression (PA-CF, couche 0,2 mm, 4 parois, 5 dessus/dessous, gyroid 25 %, sans support, buse 290 C / plateau 100 C). | LICENCE Materiel - CERN-OHL-S-2.0 Documentation - CC-BY-SA 4.0

§ 12

Annexe YAML

Extraits cles de s3-salle-de-bain.yaml

Les blocs ci-dessous sont reproduits a l'identique du fichier ESPHome de production. Pour la configuration complete (lambdas LED, scripts control_leds_*, gestion timer, automation voice assistant), se referer au fichier source s3-salle-de-bain.yaml.

esp32 - board et framework

esp32:

board: esp32-s3-devkitc-1

cpu_frequency: 240MHz

variant: esp32s3

flash_size: 16MB

framework:

type: esp-idf

version: recommended

sdkconfig_options:

CONFIG_ESP32S3_DATA_CACHE_64KB: "y"

CONFIG_ESP32S3_DATA_CACHE_LINE_64B: "y"

CONFIG_ESP32S3_INSTRUCTION_CACHE_32KB: "y"

CONFIG_SPIRAM_RODATA: "y"

CONFIG_SPIRAM_FETCH_INSTRUCTIONS: "y"

CONFIG_MBEDTLS_SSL_PROTO_TLS1_3: "y"

psram:

mode: octal

speed: 80MHz

i2s_audio - deux bus distincts

i2s_audio:

- id: i2s_output # vers PCM5102

i2s_lrclk_pin: { number: GPIO7 }

i2s_bclk_pin: { number: GPIO8 }

- id: i2s_in # depuis microphone MEMS

i2s_lrclk_pin: { number: GPIO4 }

i2s_bclk_pin: { number: GPIO5 }

microphone:

- platform: i2s_audio

i2s_audio_id: i2s_in

id: external_microphone

adc_type: external

i2s_din_pin: GPIO11

pdm: false

bits_per_sample: 32bit

speaker - mixer + resampler + DAC

speaker:

# Sortie hardware PCM5102 (16-bit 48 kHz stereo)

- platform: i2s_audio

id: i2s_audio_speaker

sample_rate: 48000

i2s_mode: primary

i2s_dout_pin: GPIO10

bits_per_sample: 16bit

dac_type: external

channel: stereo

timeout: never

buffer_duration: 100ms

# Mixer combinant annonce + media

- platform: mixer

id: mixing_speaker

output_speaker: i2s_audio_speaker

num_channels: 2

source_speakers:

- id: announcement_mixing_input

- id: media_mixing_input

# Resampler par flux applicatif

- platform: resampler

id: announcement_resampling_speaker

output_speaker: announcement_mixing_input

sample_rate: 48000

bits_per_sample: 16

- platform: resampler

id: media_resampling_speaker

output_speaker: media_mixing_input

sample_rate: 48000

bits_per_sample: 16

media_player - pipelines + ducking

media_player:

- platform: speaker

id: external_media_player

name: Media Player

volume_increment: 0.05

volume_min: 0.4

volume_max: 0.85

announcement_pipeline:

speaker: announcement_resampling_speaker

format: FLAC

num_channels: 1 # mono

sample_rate: 48000

media_pipeline:

speaker: media_resampling_speaker

format: FLAC

num_channels: 2 # stereo

sample_rate: 48000

on_announcement:

- mixer_speaker.apply_ducking:

id: media_mixing_input

decibel_reduction: 20

duration: 0.0s

micro_wake_word + selector de sensibilite

micro_wake_word:

id: mww

microphone:

microphone: external_microphone

channels: 0

gain_factor: 4

stop_after_detection: false

models:

- model: okay_nabu # kahrendt v20241226.3

- model: hey_jarvis # v2

- model: hey_mycroft # v2

- model: stop

internal: true

vad:

select:

- platform: template

name: "Wake word sensitivity"

initial_option: Slightly sensitive

options:

- Slightly sensitive # cutoffs 0.85 / 0.97 / 0.99

- Moderately sensitive # cutoffs 0.69 / 0.92 / 0.95

- Very sensitive # cutoffs 0.56 / 0.83 / 0.93

voice_assistant - pipeline complet

voice_assistant:

id: va

microphone: external_microphone

media_player: external_media_player

micro_wake_word: mww

use_wake_word: false

noise_suppression_level: 0

auto_gain: 0 dbfs

volume_multiplier: 1

on_start:

- mixer_speaker.apply_ducking:

id: media_mixing_input

decibel_reduction: 20

duration: 0.0s

on_end:

- mixer_speaker.apply_ducking:

id: media_mixing_input

decibel_reduction: 0

duration: 1.0s

CONCLUSION

Un dispositif complet, prive et extensible.

Le projet demontre qu'un ESP32-S3 peut heberger une experience vocale de bout en bout : detection de wake word locale en temps reel, pipeline audio bi-directionnel avec mixage et ducking, retour visuel de haute fidelite et integration profonde a Home Assistant via une API chiffree. Toutes les interactions physiques (bouton, encodeur, jack, switch mute) sont exposees comme entites dans HA, ouvrant la voie a des automations avancees sans aucune dependance au cloud.

COLOPHON

Module | S3 Salle de Bain - Rapport Technique v3
Auteur | Hanafi Benmesbah
Organisation | domokami
Base | s3-salle-de-bain.yaml
Depot | github.com/hanafi09/s3-salle-de-bain
Plateforme | ESPHome 2025.9.3+ / ESP32-S3 DevKitC-1
Date | 10 juin 2026

Hanafi Benmesbah

DOMOKAMI · S3 SALLE DE BAIN Rapport Technique - v3

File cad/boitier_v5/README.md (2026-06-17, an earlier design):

# Boîtier v5 — « galet intégral » (4 HP + basses)

Évolution majeure de la v4 : **forme galet très arrondie** (toutes les arêtes
adoucies) et **4 haut-parleurs** dont 2 radiateurs passifs pour le renfort de
basses. Conçu pour la carte porteuse **76,7 × 108 mm** (export JLCPCB).

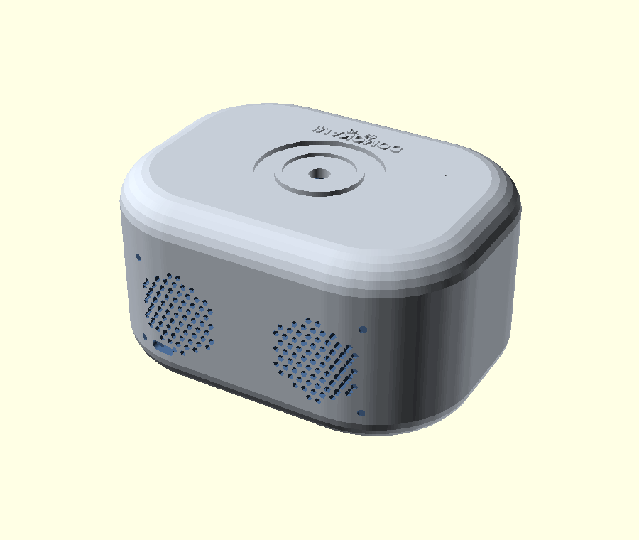
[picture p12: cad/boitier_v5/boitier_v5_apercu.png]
Aperçu


## Pièces

| Fichier | Rôle | Matière |
|---|---|---|
| `v5_base.stl` / `.step` | Bac (galet, façade + arrière HP, USB-C, entretoises) | PA-CF |
| `v5_top.stl` / `.step` | Capot (molette, anneau LED, micro, marquage relief) | PA-CF |
| `v5_speaker_gasket.stl` / `.step` | 4 joints d'enceinte (étanchéité basses) | TPU 95A |

Paramétrique : tout est piloté par **`params.scad`**.

## Acoustique — 4 HP

- **2 plein-bande 40 mm en façade** (+Y), actifs, reliés au PAM8403.
- **2 radiateurs passifs à l'arrière** (-Y) pour la **réflexion de basse** :
  aucun câblage, ils résonnent par la pression interne → **PCB inchangé**.
- **Caisson étanche** : pas d'events ; prévoir les **4 joints TPU** (compression)
  pour une vraie restitution des basses.

## Caractéristiques

- **Encombrement** : 129 × 98 × 69 mm — **carte** : 76,7 × 108 mm
- **Galet** : arêtes arrondies (fillet 12 mm), coins R36, **toutes faces adoucies**
- **Paroi / fond** : 2,6 / 7,0 mm
- **HP** : 4 × 40 mm (2 actifs façade + 2 radiateurs passifs arrière), z = 31 mm
- **USB-C** : bas de la paroi arrière (aligné sur `J2`), sous les radiateurs
- **Encodeur** : EC11 monté sur le capot (douille M7), câblé au PCB
- **Anneau LED** WS2812 : Ø 44 / 30 mm
- **Micro** : pinhole Ø 0,8 mm au-dessus de l'INMP441
- **Marquage** : DOMOKAMI + S3 v5 **en relief** sur le capot (côté façade)
- **Fermeture** : lèvre press-fit (sans vis) + encoche de démontage latérale
- **Fixation PCB** : 4 × M3 sur entretoises, trous réels `MK1`–`MK4`
- **Montage HP** : par l'intérieur, 4 avant-trous M2.5 par HP (façade nette)

> Boîtier obtenu par rotation −90° de la carte (HP façade +Y / USB-C arrière −Y).
> Le STEP du bac utilise des ouvertures HP circulaires + `$fn` réduit (valide & léger).

## Impression (RatRig V-Core 3 400, buse 0,4)

PA-CF, couche 0,2 mm, 4 périmètres, 5 dessus/dessous, gyroïde 25 %, **sans
support**, buse 290 °C / plateau 100 °C. Projet OrcaSlicer prêt : `boitier_v5.3mf`.
Joints HP en **TPU 95A**. La v4 reste disponible dans `cad/boitier_v4/`.

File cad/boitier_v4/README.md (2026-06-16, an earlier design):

# Boîtier v4 — « galet rectangulaire arrondi »

Boîtier **conçu pour la carte porteuse KiCad 76,7 × 108 mm** de ce dépôt
(implantation relue directement depuis `s3-salle-de-bain.kicad_pcb`, version
exportée pour JLCPCB). Remplace l'ancien boîtier cylindrique Ø110 mm, désormais
en *legacy* dans `cad/`. Design *classe & épuré* : galet compact à coins
arrondis, molette centrée, haut-parleurs en façade, **dessus sans vis**.

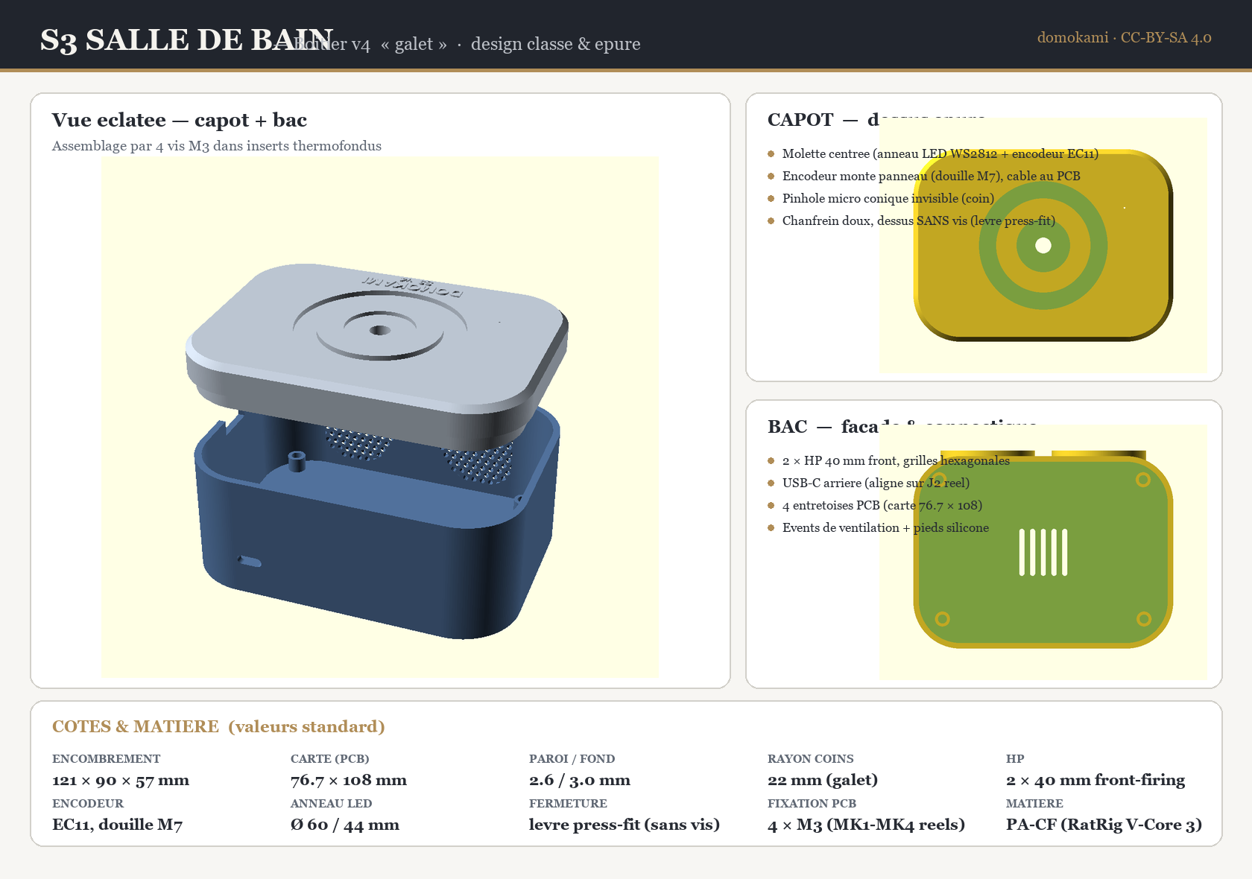
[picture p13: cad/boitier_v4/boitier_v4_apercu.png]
Aperçu


## Pièces

| Fichier | Rôle | Matière conseillée |
|---|---|---|
| `v4_base.stl` / `.step` | Bac (parois, façade HP, USB-C, entretoises PCB) | PA-CF |
| `v4_top.stl` / `.step` | Capot (molette, anneau LED, micro, lèvre) | PA-CF |
| `v4_speaker_gasket.stl` / `.step` | 2 joints d'enceinte (compression) | TPU 95A |

Les `.scad` sont paramétriques : tout est piloté par **`params.scad`**.
`v4_assembly.scad` (éclaté) et `v4_section.scad` (coupe) sont des vues de
contrôle, pas des pièces à imprimer.

### Fichiers STEP (CAO / partage fabricant)

OpenSCAD **n'exporte pas le STEP** (géométrie maillée, pas de B-rep). Les `.step`
fournis sont des **solides B-rep facettés** reconstruits depuis les STL via
FreeCAD. Les trois sont **valides et fermés** (un solide chacun, sauf le joint
= 2 solides), légers, importables dans tout MCAD ou chez un fabricant :

| STEP | État | Taille |
|---|---|---|
| `v4_base.step` | ✅ valide, fermé | ~2,5 Mo |
| `v4_top.step` | ✅ valide, fermé | ~3,2 Mo |
| `v4_speaker_gasket.step` | ✅ valide (2 solides) | ~2,4 Mo |

> **Note bac** : le STEP du bac utilise des **ouvertures HP circulaires** (et un
> `$fn` réduit) au lieu des grilles hexagonales — c'est ce qui le rend valide et
> léger (2,5 Mo au lieu de 23 Mo). Les **grilles hexagonales restent dans le STL
> d'impression et le `.scad`** (variable `grille_simple`). Pour l'impression,
> utiliser les `.stl` / `.scad` ; le STEP sert de référence CAO / fabricant.
>
> Régénérer : capot+joint via `freecadcmd stl_to_step.py` ; bac via
> `openscad -D grille_simple=true -D '$fn=48' -o v4_base_step.stl v4_base.scad`
> puis `freecadcmd base_simple_to_step.py`. Pour de l'édition paramétrique,
> **privilégier les `.scad`**.

## Caractéristiques

- **Encombrement** : 121 × 90 × 57 mm — **carte** : 76,7 × 108 mm
- **Paroi / fond** : 2,6 / 3,0 mm · **rayon des coins** : 22 mm
- **Haut-parleurs** : 2 × 40 mm *front-firing*, grilles hexagonales + anneaux M2.5
- **Encodeur** : EC11 **monté sur le capot** (douille M7), relié par fil aux
  connecteurs `SW1` / `DS1` de la carte. *(Un EC11 soudé sur le PCB ne pourrait
  pas atteindre le dessus situé ~50 mm plus haut.)*
- **Anneau LED** WS2812 : Ø 60 / 44 mm, gorge diffuseur
- **Micro** : pinhole conique Ø 0,8 mm, placé **au-dessus du module INMP441**
- **USB-C** : découpe alignée sur le connecteur `J2` réel de la carte
- **Marquage** : logo **DOMOKAMI** + version **S3 v4** **en relief sur le capot**
  (sous la molette, côté façade, lisibles face à l'utilisateur), paramétrables
  dans `params.scad` (`brand_*`)
- **Fermeture** : lèvre périphérique en **press-fit** (jeu 0,15 mm), aucune vis
  visible + encoche de démontage latérale
- **Fixation PCB** : 4 × M3 sur entretoises, alignées sur les **4 trous réels
  `MK1`–`MK4`** de la carte. Positions relues via `kicad/dump_pcb_geo.py` :
  PCB (73.37, 43.90) · (138.43, 44.28) · (138.43, 139.41) · (73.37, 137.90)

> Le boîtier est obtenu par **rotation −90°** de la carte (HP en façade +Y,
> USB-C à l'arrière −Y) ; le mapping carte→boîtier est documenté en tête de
> `params.scad`.

## Impression (RatRig V-Core 3 400, buse 0,4)

PA-CF, couche 0,2 mm, 4 périmètres, 5 couches dessus / dessous, remplissage
25 % gyroïde, **sans support** (lèvre et grilles auto-portées), bord (brim)
auto 8 mm. Buse 290 °C, plateau 100 °C, ventilation 10–30 %.

> Le projet OrcaSlicer prêt à trancher est fourni dans
> `cad/boitier_v4/boitier_v4.3mf` (mêmes réglages PA-CF que `boitier_base_optimise`).

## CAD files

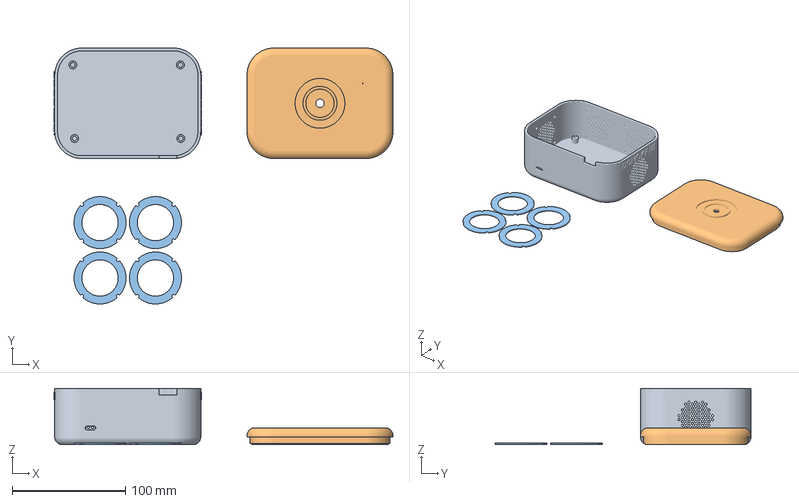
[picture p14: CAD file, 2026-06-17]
cad/boitier_v6/boitier_v6.3mf
299.8 x 226.4 x 50.0 mm
v6_base.stl
v6_top.stl
v6_speaker_gasket.stl

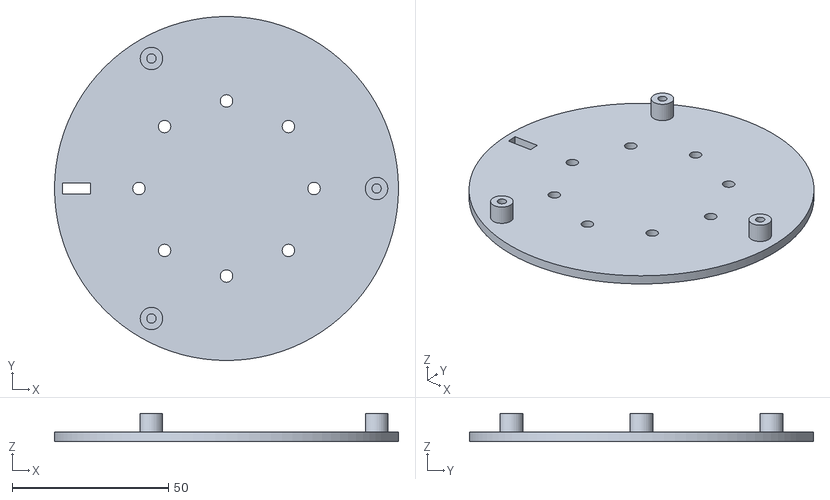
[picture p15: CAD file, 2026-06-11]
cad/housing_bottom.stl
110.0 x 110.0 x 9.00

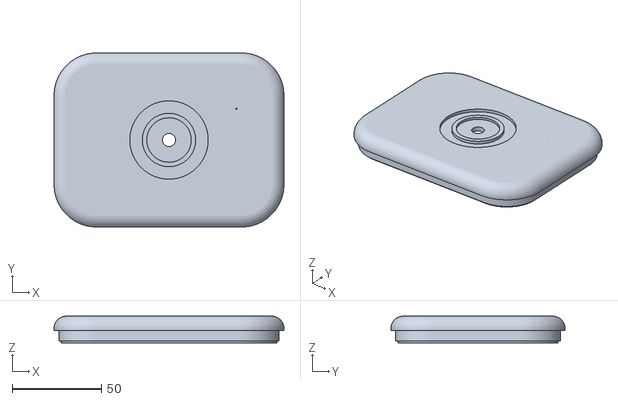
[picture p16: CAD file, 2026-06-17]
cad/boitier_v6/v6_top.stl
129.1 x 97.8 x 15.0

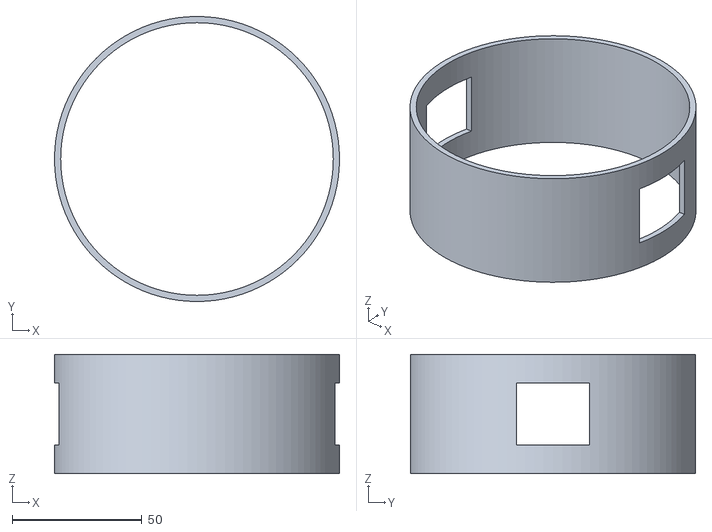
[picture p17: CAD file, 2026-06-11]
cad/housing_body.stl
110.0 x 110.0 x 46.0

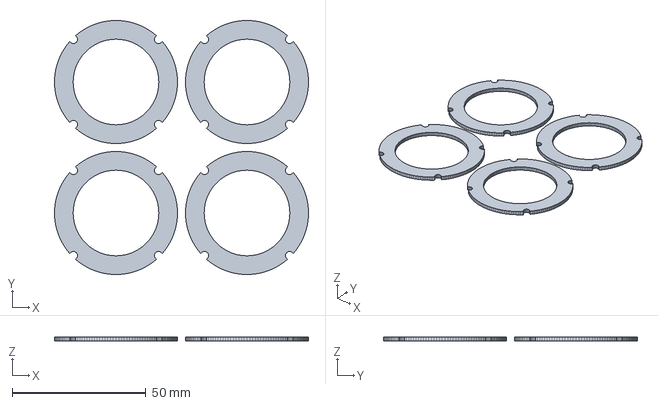
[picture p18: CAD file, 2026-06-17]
cad/boitier_v6/v6_speaker_gasket.step
95.0 x 95.0 x 1.60 mm

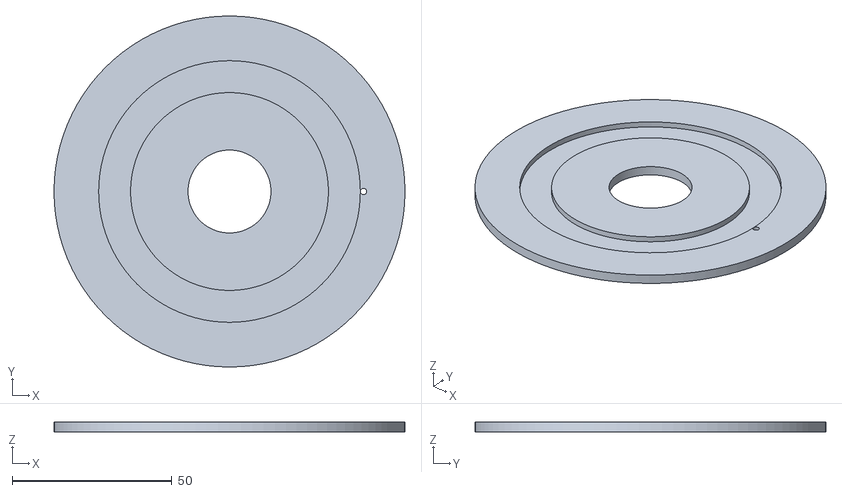
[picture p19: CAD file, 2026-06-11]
cad/housing_top.stl
110.0 x 110.0 x 3.00

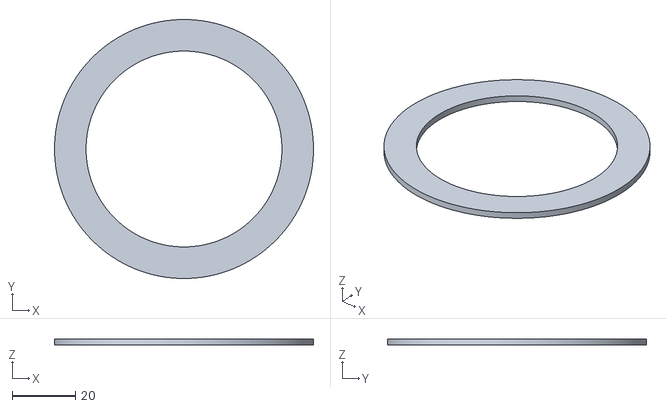
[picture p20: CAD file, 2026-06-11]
cad/diffuser_ring.stl
82.0 x 82.0 x 2.00

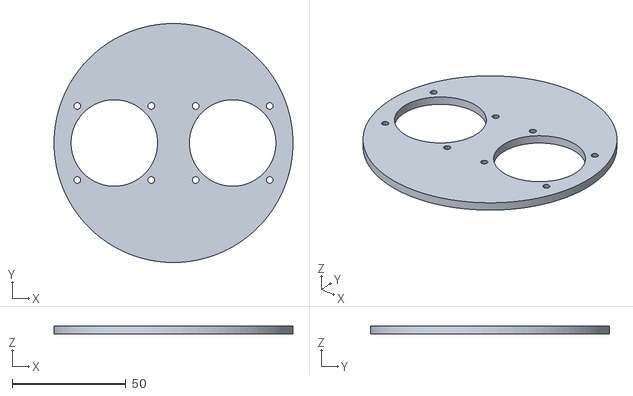
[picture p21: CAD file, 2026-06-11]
cad/speaker_baffle.stl
105.0 x 105.0 x 3.50

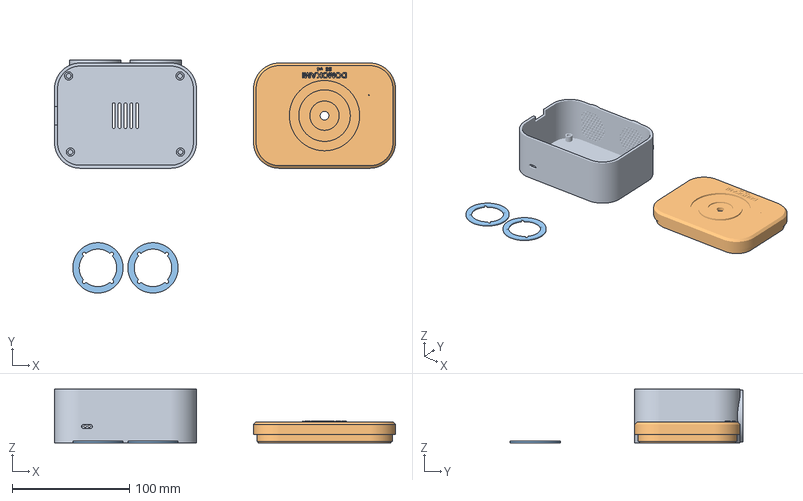
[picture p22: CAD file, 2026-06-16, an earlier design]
cad/boitier_v4/boitier_v4.3mf
291.2 x 199.0 x 46.0 mm
v4_base.stl
v4_top.stl
v4_speaker_gasket.stl

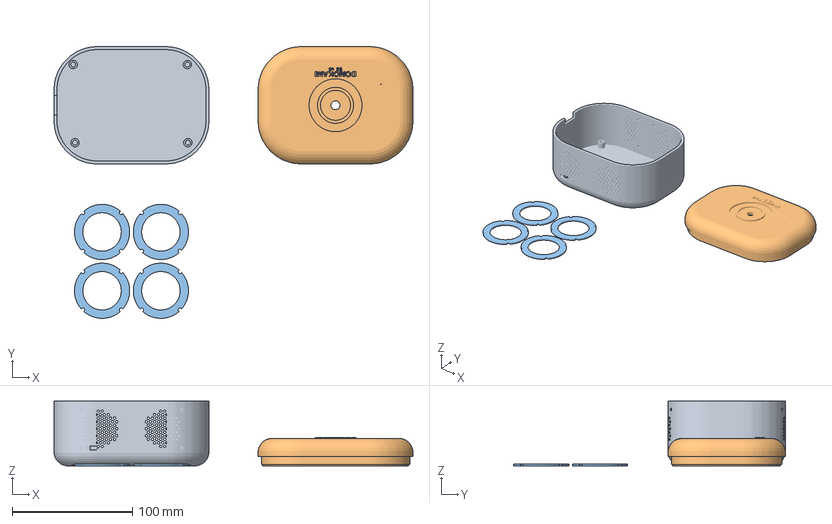
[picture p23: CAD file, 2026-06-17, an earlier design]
cad/boitier_v5/boitier_v5.3mf
299.1 x 226.4 x 53.9 mm
v5_base.stl
v5_top.stl
v5_speaker_gasket.stl

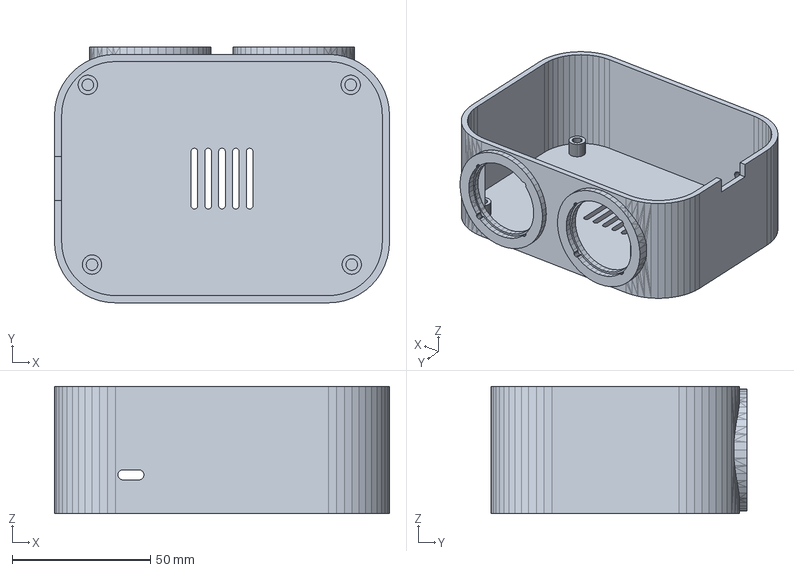
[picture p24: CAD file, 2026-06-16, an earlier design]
cad/boitier_v4/v4_base.step
121.2 x 92.5 x 46.0 mm

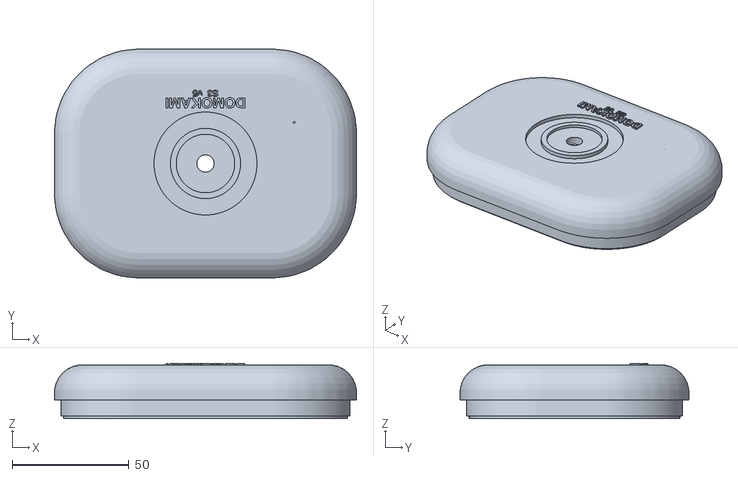
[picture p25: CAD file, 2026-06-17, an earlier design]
cad/boitier_v5/v5_top.stl
129.1 x 97.7 x 23.6

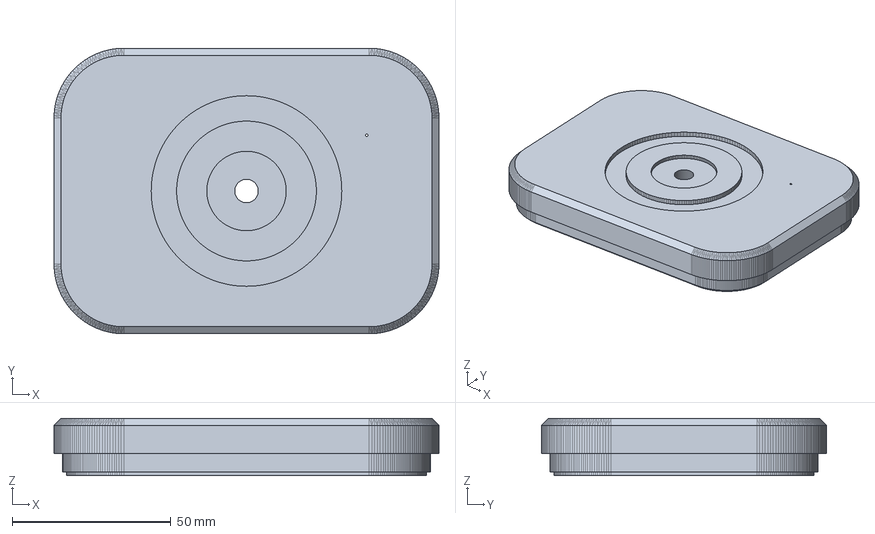
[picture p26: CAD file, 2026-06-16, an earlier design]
cad/boitier_v4/v4_top.step
121.2 x 89.9 x 18.0 mm

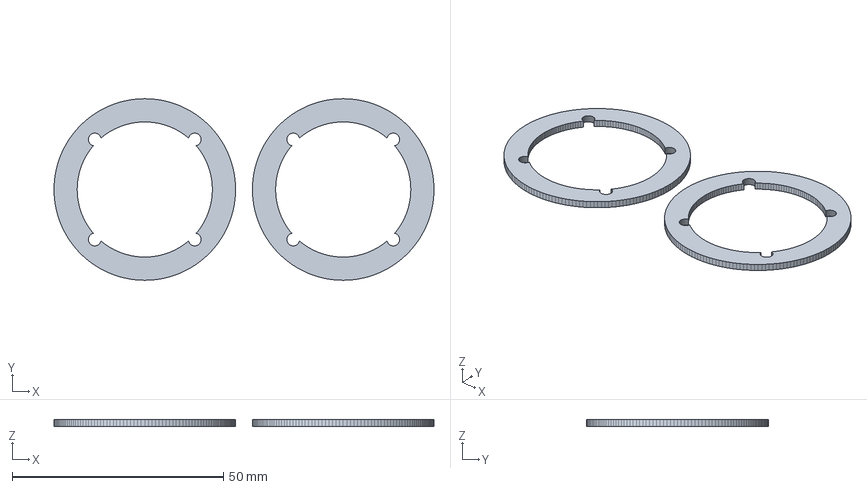
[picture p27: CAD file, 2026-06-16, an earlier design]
cad/boitier_v4/v4_speaker_gasket.step
90.0 x 43.0 x 1.60 mm

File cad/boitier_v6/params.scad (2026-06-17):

// ============================================================
// S3 Salle de Bain - Boitier v6  "JBL Go/Clip" : plat, large, epure
//  - 2 HP plein-bande actifs en FACADE (+Y), 2 grilles rondes
//  - 2 RADIATEURS PASSIFS sur les 2 BOUTS (+-X) avec logo DOMOKAMI grave
//  - USB-C seul a l'arriere (-Y) -> plus de chevauchement avec un HP
//  - caisson etanche, carte 76,7 x 108 mm (export JLCPCB)
// ============================================================

$fn = 140;

grille_simple = false;   // true (STEP) -> ouvertures circulaires simples

// --- Carte (PCB porteuse KiCad, rotation -90deg) ---
pcb_l = 108.03; pcb_w = 76.69;
pcb_clear = 8; pcb_standoff = 6; pcb_hole_d = 3.2; pcb_insert_d = 4.2;
pcb_mounts = [ [ 46.96, -31.13], [ 46.58,  33.93],
               [-48.55,  33.93], [-47.04, -31.13] ];

// --- Coque (plate & large, bords adoucis) ---
wall = 2.6; corner_r = 24; fillet = 7; floor_th = 5.0;
inner_l = pcb_l + 2*pcb_clear;   // 124.03
inner_w = pcb_w + 2*pcb_clear;   // 92.69
outer_l = inner_l + 2*wall;      // ~129.2  (large, axe X)
outer_w = inner_w + 2*wall;      // ~97.9   (profondeur, axe Y)
base_h = 50; top_h = 8; total_h = base_h + top_h;   // 58 (plat & large)

// --- Molette centrale (encodeur EC11 + anneau LED) ---
enc_bushing_d = 7.4; enc_knob_d = 22; enc_knob_recess = 1.4; enc_pos = [0,0];
led_outer = 44; led_inner = 30; led_groove = 1.8; led_pos = [0,0];

// --- Micro (pinhole au-dessus de l'INMP441) ---
mic_pos = [37.86, 17.58]; mic_hole_d = 0.8; mic_cone_d = 3.0; mic_cone_h = 1.8;

// --- Haut-parleurs 40 mm ---
spk_outer = 40; spk_cone = 33; spk_bolt_circle = 45; spk_screw_d = 2.6;
spk_grille_hole = 2.2; spk_grille_gap = 3.4;
spk_spacing = 52;          // entraxe des 2 HP facade (x = +-26)
spk_center_z = 24;         // hauteur du centre des HP (boitier plat)
// HP actifs facade (paroi +Y) : [x, signe]
front_spk = [ [-spk_spacing/2, +1], [ spk_spacing/2, +1] ];
// radiateurs passifs sur les bouts (parois +-X) : signe X
end_rad   = [ +1, -1 ];

// --- USB-C (arriere -Y, sur J2, SEUL -> aucun chevauchement) ---
usb_w = 9.4; usb_h = 3.6; usb_z = 15; usb_x = -32.95;

// --- Fermeture capot : levre press-fit ---
lip_h = 7; lip_clear = 0.15;

// --- Pieds silicone ---
foot_d = 12; foot_recess = 0.8; foot_inset = 20;

// --- Marquage ---
brand_text = "DOMOKAMI"; brand_version = "S3  v6";
brand_relief = 0.6; brand_depth = 0.6;
brand_font = "Liberation Sans:style=Bold";
brand_top_size = 4.0;      // petite version sur le dessus
brand_end_size = 7.5;      // logo sur les bouts (facon JBL), plus gros
brand_top_pos1 = [0, 26];  // (logo top optionnel)
brand_top_pos2 = [0, 31];

// ============================================================
// Helpers
// ============================================================
module rounded_rect(l, w, r) {
    hull() for (sx=[-1,1], sy=[-1,1])
        translate([sx*(l/2-r), sy*(w/2-r)]) circle(r=r);
}
module rounded_box(l, w, h, r) { linear_extrude(height=h) rounded_rect(l, w, r); }
module pebble_body(l, w, h, rc, fil) {
    minkowski() {
        translate([0,0,fil]) rounded_box(l-2*fil, w-2*fil, h-2*fil, max(0.8, rc-fil));
        sphere(r=fil, $fn=28);
    }
}
// Grille hexagonale : uniquement hexagones ENTIERS (bord net)
module hex_grille(diam, hole_d, gap) {
    R = diam/2 - hole_d/2; rows = ceil(diam/gap)+2;
    for (iy=[-rows:rows]) {
        yo = iy*gap*0.866; xo = (iy%2==0)?0:gap/2;
        for (ix=[-rows:rows]) {
            cx = ix*gap+xo; cy = yo;
            if (cx*cx + cy*cy <= R*R) translate([cx,cy]) circle(d=hole_d, $fn=6);
        }
    }
}

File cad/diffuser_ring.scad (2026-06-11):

// ============================================================
// S3 Salle de Bain - Boitier voice assistant
// Piece : ANNEAU DIFFUSEUR LED (PETG TRANSLUCIDE)
// Auteur : Hanafi BENMESBAH / domokami
// ============================================================

$fn = 256;

outer_d = 82;
inner_d = 62;
height = 2.0;
lip_h = 0.8;
lip_thickness = 0.8;

module ring() {
    difference() {
        union() {
            // Anneau principal
            difference() {
                cylinder(d = outer_d, h = height);
                translate([0,0,-0.1])
                    cylinder(d = inner_d, h = height + 0.2);
            }
            // Levre de maintien interne
            translate([0,0,-lip_h])
                difference() {
                    cylinder(d = inner_d + lip_thickness*2, h = lip_h);
                    translate([0,0,-0.1])
                        cylinder(d = inner_d, h = lip_h + 0.2);
                }
        }
    }
}

ring();

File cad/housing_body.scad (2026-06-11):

// ============================================================
// S3 Salle de Bain - Boitier voice assistant
// Piece : CORPS CYLINDRIQUE (avec grilles stereo + mute switch)
// Auteur : Hanafi BENMESBAH / domokami
// ============================================================

$fn = 160;

// --- Parametres ---
outer_diameter = 110;
height = 46;          // corps sans capot ni fond
wall = 2.4;

// Grilles stereo laterales (motif hexagonal)
grille_center_z = height/2;
grille_w = 55;        // largeur arc
grille_h = 28;        // hauteur fenetre
grille_angle = 95;    // ouverture angulaire par cote

// Decoupes hexagones
hex_size = 4.0;       // rayon circonscrit
hex_spacing = 9.0;    // pas

// Interrupteur mute (fente laterale)
mute_angle = 180;     // arriere gauche
mute_w = 9;
mute_h = 4;
mute_z = height - 10;

// Jack 3.5 mm (face avant, bas)
jack_d = 6.5;
jack_z = 10;
jack_angle = 0;       // face avant

// LED indicator
led_ind_d = 2.0;
led_ind_z = 8;
led_ind_angle = 0;
led_ind_offset = 18;  // decale de l'axe

// Clips recess (3 x 120 deg) pour s'emboiter avec capot
clip_slot_w = 6.2;
clip_slot_h = 10.2;
clip_slot_depth = 2.6;

// ============================================================

module hex_cell(size) {
    rotate([0,0,30])
        circle(d = size*2, $fn = 6);
}

module hex_grid_pattern(w, h, s, spacing) {
    rows = ceil(h / (spacing*0.866)) + 1;
    cols = ceil(w / spacing) + 1;
    for (r = [0:rows]) {
        for (c = [0:cols]) {
            x = c*spacing + (r%2)*(spacing/2) - w/2;
            y = r*spacing*0.866 - h/2;
            if (abs(x) < w/2 - s/2 && abs(y) < h/2 - s/2)
                translate([x, y, 0]) hex_cell(s);
        }
    }
}

module stereo_grille(side_angle) {
    rotate([0,0,side_angle]) {
        translate([outer_diameter/2 - wall/2, 0, grille_center_z])
            rotate([0,90,0])
                linear_extrude(height = wall + 2, center = true)
                    hex_grid_pattern(grille_w, grille_h, hex_size, hex_spacing);
    }
}

module body() {
    difference() {
        // Tube principal
        difference() {
            cylinder(d = outer_diameter, h = height);
            translate([0,0,-0.1])
                cylinder(d = outer_diameter - 2*wall, h = height + 0.2);
        }

        // Grilles stereo gauche & droite
        stereo_grille(90);
        stereo_grille(-90);

        // Fente switch mute
        rotate([0,0,mute_angle])
            translate([outer_diameter/2 - wall, -mute_w/2, mute_z])
                cube([wall + 2, mute_w, mute_h]);

        // Jack 3.5 mm face avant
        rotate([0,0,jack_angle])
            translate([outer_diameter/2 - wall - 0.1, 0, jack_z])
                rotate([0,90,0])
                    cylinder(d = jack_d, h = wall + 2);

        // LED indicator
        rotate([0,0,led_ind_angle])
            translate([outer_diameter/2 - wall - 0.1, led_ind_offset, led_ind_z])
                rotate([0,90,0])
                    cylinder(d = led_ind_d, h = wall + 2);

        // Clips superieurs (recess intern pour lugs du capot)
        for (a = [0, 120, 240]) {
            rotate([0,0,a])
                translate([outer_diameter/2 - wall - clip_slot_depth,
                           -clip_slot_w/2,
                           height - clip_slot_h])
                    cube([clip_slot_depth + 0.1, clip_slot_w, clip_slot_h + 0.1]);
        }
    }
}

body();

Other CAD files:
cad/boitier_v5/v5_speaker_gasket.step
cad/boitier_v5/v5_base.step
cad/housing_bottom.scad
cad/boitier_v4/params.scad
cad/boitier_v4/v4_assembly.scad
cad/boitier_v4/v4_base.scad
cad/boitier_v4/v4_base.stl
cad/boitier_v4/v4_section.scad
cad/boitier_v4/v4_speaker_gasket.scad
cad/boitier_v4/v4_speaker_gasket.stl
cad/boitier_v4/v4_top.scad
cad/boitier_v4/v4_top.stl
cad/boitier_v5/params.scad
cad/boitier_v5/v5_assembly.scad
cad/boitier_v5/v5_base.scad
cad/boitier_v5/v5_base.stl
cad/boitier_v5/v5_speaker_gasket.stl
cad/boitier_v5/v5_top.scad
cad/boitier_v6/v6_assembly.scad
cad/boitier_v6/v6_base.scad
cad/boitier_v6/v6_speaker_gasket.scad
cad/boitier_v6/v6_speaker_gasket.stl
cad/boitier_v6/v6_top.scad
cad/housing_top.scad
cad/speaker_baffle.scad

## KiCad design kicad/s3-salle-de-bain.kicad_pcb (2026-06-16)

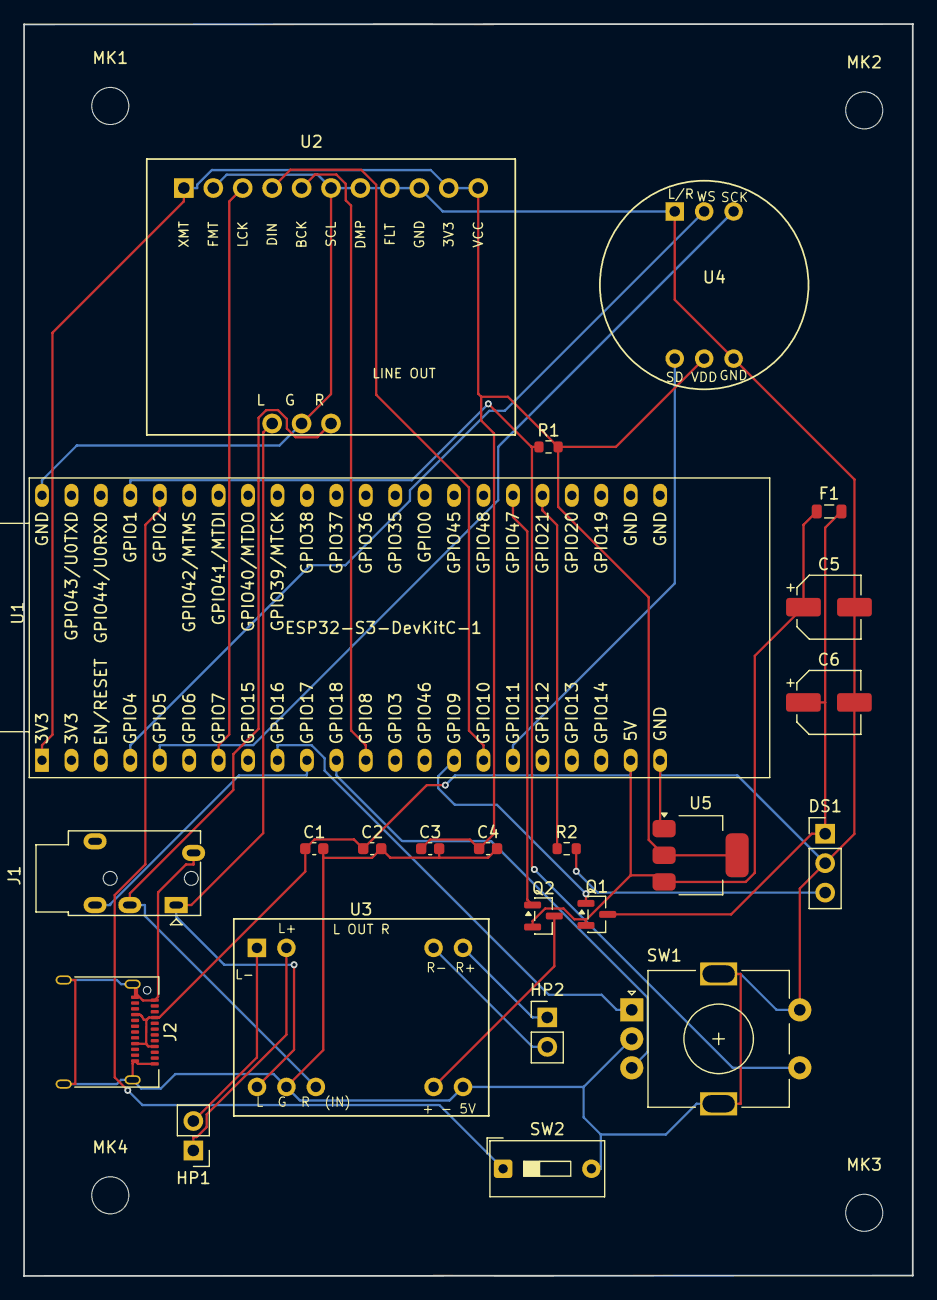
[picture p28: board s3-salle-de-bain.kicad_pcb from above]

Board: 2 copper layers, 76.7 x 108.0 mm, 27 parts (0 on the bottom side), 26 nets.

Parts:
C1, C3, C4: 10uF; C_0603_1608Metric
C2: 100nF; C_0603_1608Metric
C5: 100uF; CP_Elec_5x5.3
C6: 470uF; CP_Elec_5x5.3
DS1: WS2812-Ring; PinHeader_1x03_P2.54mm_Vertical
F1: Ferrite 600R; L_0805_2012Metric
HP1: HP-Left; PinHeader_1x02_P2.54mm_Vertical
HP2: HP-Right; PinHeader_1x02_P2.54mm_Vertical
J1: Jack-3.5mm; Jack_3.5mm_PJ320E_Horizontal
J2: USB-C; USB_C_Receptacle_Amphenol_12401610E4-2A
MK1, MK2, MK3, MK4: M3; MountingHole_3.2mm_M3
Q1, Q2: AO3401; SOT-23
R1: 10k; R_0603_1608Metric
R2: 330; R_0603_1608Metric
SW1: EC11; RotaryEncoder_Alps_EC11E-Switch_Vertical_H20mm
SW2: Mute-SPDT; SW_DIP_SPSTx01_Slide_9.78x4.72mm_W7.62mm_P2.54mm
U1: ESP32-S3-DevKitC-1; ESP32-S3-DevKitC
U2: GY-PCM5102
U3: PAM8403; PAM8403-mini
U4: INMP441; GY-INMP441
U5: AMS1117-3.3; SOT-223-3_TabPin2

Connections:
+3V3: C3.1, C4.1, R1.2, U1.1, U2.1, U2.10, U2.11, U4.5, U5.2
+5V: C1.1, C2.1, C5.1, F1.1, J2.A4, J2.A9, J2.B4, J2.B9, Q1.2, Q2.2, U1.21, U5.3
+5V_AMP: Q2.3, U3.V+
+5V_LED: C6.1, DS1.1, F1.2, Q1.3
AMP_EN: Q2.1, U1.28
AUDIO_L: J1.T, U2.L, U3.LI
AUDIO_R: J1.R1, U2.R, U3.RI
BTN_CENTER: R1.1, SW1.S1, U1.41
DAC_BCK: U1.12, U2.5
DAC_DIN: U1.16, U2.4
DAC_LRCK: U1.7, U2.3
ENC_A: SW1.A, U1.9
ENC_B: SW1.B, U1.11
GND: C1.2, C2.2, C3.2, C4.2, C5.2, C6.2, DS1.2, J1.S, J2.A1, J2.A12, J2.B1, J2.B12, J2.SH, SW1.C, SW1.MP, SW1.S2, SW2.2, U1.22, U1.44, U2.2, U2.6, U2.7, U2.8, U2.9, U2.G, U3.GI, U3.V-, U4.1, U4.6, U5.1
JACK_DET: J1.R2, U1.10
LED_DIN: DS1.3, R2.2
LED_DIN_RAW: R2.1, U1.27
LED_PWR_EN: Q1.1, U1.15
MIC_BCLK: U1.5, U4.3
MIC_DIN: U1.17, U4.4
MIC_LRCLK: U1.4, U4.2
MUTE_SW: SW2.1, U1.40
SPK_L+: HP1.1, U3.L+
SPK_L-: HP1.2, U3.L-
SPK_R+: HP2.1, U3.R+
SPK_R-: HP2.2, U3.R-

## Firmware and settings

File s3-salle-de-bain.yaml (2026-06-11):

# =============================================================================
# S3 Salle de Bain - Voice Assistant ESP32-S3
# Auteur  : Hanafi BENMESBAH / domokami
# Source  : https://github.com/hanafi09/s3-salle-de-bain
# Licence : CERN-OHL-S-2.0 (firmware + materiel) / CC-BY-SA-4.0 (docs + CAO)
# =============================================================================
# Diff applique vs version initiale :
#   - Secrets externalises dans secrets.yaml (voir secrets.example.yaml)
#   - Fix script.control_leds_timer_ticking : effect "Timer tick" -> "Timer Tick"
#     (ESPHome est case-sensitive sur les noms d'effets light)
# =============================================================================

esphome:
  name: s3-salle-de-bain
  friendly_name: S3 Salle de Bain
  name_add_mac_suffix: false
  min_version: 2025.9.3
  on_boot:
    priority: 375
    then:
      - script.execute: control_leds
      - delay: 1s
      - switch.turn_on: internal_speaker_amp
      - delay: 10min
      - if:
          condition:
            lambda: return id(init_in_progress);
          then:
            - lambda: id(init_in_progress) = false;
            - script.execute: control_leds

esp32:
  board: esp32-s3-devkitc-1
  cpu_frequency: 240MHz
  variant: esp32s3
  flash_size: 16MB
  framework:
    type: esp-idf
    version: recommended
    sdkconfig_options:
      CONFIG_ESP32S3_DATA_CACHE_64KB: "y"
      CONFIG_ESP32S3_DATA_CACHE_LINE_64B: "y"
      CONFIG_ESP32S3_INSTRUCTION_CACHE_32KB: "y"
      CONFIG_SPIRAM_RODATA: "y"
      CONFIG_SPIRAM_FETCH_INSTRUCTIONS: "y"
      CONFIG_BT_ALLOCATION_FROM_SPIRAM_FIRST: "y"
      CONFIG_BT_BLE_DYNAMIC_ENV_MEMORY: "y"
      CONFIG_MBEDTLS_EXTERNAL_MEM_ALLOC: "y"
      CONFIG_MBEDTLS_SSL_PROTO_TLS1_3: "y"

wifi:
  id: wifi_id
  ssid: !secret wifi_ssid
  password: !secret wifi_password
  fast_connect: true
  power_save_mode: NONE
  manual_ip:
    static_ip: 192.168.1.197
    gateway: 192.168.1.254
    subnet: 255.255.255.0
    dns1: 192.168.1.254
    dns2: 8.8.8.8
  ap:
    ssid: "Voice-S3-Fallback"
    password: !secret fallback_password

api:
  id: api_id
  encryption:
    key: !secret api_encryption_key
  reboot_timeout: 15min

ota:
  - platform: esphome
    password: !secret ota_password
    port: 3232

captive_portal:

mdns:
  disabled: false

web_server:
  port: 80
  version: 2
  include_internal: true
  ota: false

substitutions:
  voice_assist_idle_phase_id: '1'
  voice_assist_waiting_for_command_phase_id: '2'
  voice_assist_listening_for_command_phase_id: '3'
  voice_assist_thinking_phase_id: '4'
  voice_assist_replying_phase_id: '5'
  voice_assist_not_ready_phase_id: '10'
  voice_assist_error_phase_id: '11'
  hidden_ssid: "false"
  jack_connected_sound_file: https://github.com/esphome/home-assistant-voice-pe/raw/dev/sounds/jack_connected.flac
  jack_disconnected_sound_file: https://github.com/esphome/home-assistant-voice-pe/raw/dev/sounds/jack_disconnected.flac
  mute_switch_on_sound_file: https://github.com/esphome/home-assistant-voice-pe/raw/dev/sounds/mute_switch_on.flac
  mute_switch_off_sound_file: https://github.com/esphome/home-assistant-voice-pe/raw/dev/sounds/mute_switch_off.flac
  timer_finished_sound_file: https://github.com/esphome/home-assistant-voice-pe/raw/dev/sounds/timer_finished.flac
  wake_word_triggered_sound_file: https://github.com/esphome/home-assistant-voice-pe/raw/dev/sounds/wake_word_triggered.flac
  center_button_press_sound_file: https://github.com/esphome/home-assistant-voice-pe/raw/dev/sounds/center_button_press.flac
  center_button_double_press_sound_file: https://github.com/esphome/home-assistant-voice-pe/raw/dev/sounds/center_button_double_press.flac
  center_button_triple_press_sound_file: https://github.com/esphome/home-assistant-voice-pe/raw/dev/sounds/center_button_triple_press.flac
  center_button_long_press_sound_file: https://github.com/esphome/home-assistant-voice-pe/raw/dev/sounds/center_button_long_press.flac

# I2C removed - not needed with PCM5102

psram:
  mode: octal
  speed: 80MHz
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

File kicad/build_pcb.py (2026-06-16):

# -*- coding: utf-8 -*-
"""
Build a real KiCad PCB using the pcbnew API (run with KiCad's bundled python).

Each component gets its REAL footprint loaded from the installed KiCad
footprint libraries, placed on the board, with nets assigned to pads.

Run:
  "C:\\Program Files\\KiCad\\10.0\\bin\\python.exe" build_pcb.py
"""
import os
import pcbnew

FPBASE = r"C:\Program Files\KiCad\10.0\share\kicad\footprints"
OUT = os.path.join(os.path.dirname(os.path.abspath(__file__)), "s3-salle-de-bain.kicad_pcb")

def MM(v): return pcbnew.FromMM(v)
def VEC(x, y): return pcbnew.VECTOR2I(MM(x), MM(y))

# (ref, lib, footprint, x, y, rot_deg, value, {pad_number: net_name})
# Modules are represented as pin headers (they plug into female headers).
# Discrete ICs/parts use their real SMD/THT packages.
COMPONENTS = [
    # --- ESP32-S3 DevKitC-1 : official Espressif footprint, real pinout ---
    # Pad numbers map to GPIOs per the Espressif silk:
    #   pad1=3V3, pad4=GPIO4, pad5=GPIO5, pad7=GPIO7, pad9=GPIO16, pad10=GPIO17,
    #   pad11=GPIO18, pad12=GPIO8, pad15=GPIO9, pad16=GPIO10, pad17=GPIO11,
    #   pad21=5V, pad22/23/24/44=GND, pad27=GPIO21, pad28=GPIO47,
    #   pad40=GPIO2, pad41=GPIO1
    ("U1", "Espressif", "ESP32-S3-DevKitC",
     12, 18, 0, "ESP32-S3-DevKitC-1", {
        "1":"+3V3",        # 3V3
        "4":"MIC_LRCLK",   # GPIO4
        "5":"MIC_BCLK",    # GPIO5
        "7":"DAC_LRCK",    # GPIO7
        "9":"ENC_A",       # GPIO16
        "10":"JACK_DET",   # GPIO17
        "11":"ENC_B",      # GPIO18
        "12":"DAC_BCK",    # GPIO8
        "15":"LED_PWR_EN", # GPIO9
        "16":"DAC_DIN",    # GPIO10
        "17":"MIC_DIN",    # GPIO11
        "21":"+5V",        # 5V
        "22":"GND",        # GND
        "27":"LED_DIN_RAW",# GPIO21
        "28":"AMP_EN",     # GPIO47
        "40":"MUTE_SW",    # GPIO2
        "41":"BTN_CENTER", # GPIO1
        "44":"GND",        # GND
     }),
    # --- PCM5102 DAC : GY-PCM5102 / WCMCU module (real 1x11 header + L/G/R) ---
    # Top header L->R: XMT FMT LCK DIN BCK SCL DMP FLT GND 3V3 VCC ; bottom: L G R
    ("U2", "Modules", "GY-PCM5102",
     60, 30, 0, "GY-PCM5102", {
        "1":"+3V3",       # XMT  (soft-mute -> tie high = un-muted)
        "2":"GND",        # FMT  (I2S format)
        "3":"DAC_LRCK",   # LCK  (LRCK / word select, GPIO7)
        "4":"DAC_DIN",    # DIN  (data in, GPIO10)
        "5":"DAC_BCK",    # BCK  (bit clock, GPIO8)
        "6":"GND",        # SCL  (system clock -> GND = internal PLL)
        "7":"GND",        # DMP  (de-emphasis off)
        "8":"GND",        # FLT  (normal latency)
        "9":"GND",        # GND
        "10":"+3V3",      # 3V3
        "11":"+3V3",      # VCC  (onboard LDO; 3.3-5V tolerant)
        "L":"AUDIO_L",    # line-out L
        "G":"GND",        # line-out ground
        "R":"AUDIO_R",    # line-out R
     }),
    # --- PAM8403 mini module (real board: BTL outputs L-/L+/R-/R-, no SHDN) ---
    # Top: L OUT R ; bottom-left audio IN L G R ; bottom-right power + - (5V)
    ("U3", "Modules", "PAM8403-mini",
     66, 64, 0, "PAM8403", {
        "L-":"SPK_L-","L+":"SPK_L+","R-":"SPK_R-","R+":"SPK_R+",  # BTL speaker out
        "LI":"AUDIO_L","GI":"GND","RI":"AUDIO_R",                # audio in
        "V+":"+5V_AMP","V-":"GND",                               # power (gated by Q2)
     }),
    # --- INMP441 round MEMS mic module (2x3: L/R WS SCK / SD VDD GND) ---
    ("U4", "Modules", "GY-INMP441",
     44, 6, 0, "INMP441", {
        "1":"GND",        # L/R -> GND (left channel, mono)
        "2":"MIC_LRCLK",  # WS  (GPIO4)
        "3":"MIC_BCLK",   # SCK (GPIO5)
        "4":"MIC_DIN",    # SD  (GPIO11)
        "5":"+3V3",       # VDD
        "6":"GND",        # GND
     }),
    # --- AMS1117-3.3 LDO : SOT-223 (pin2 = tab = VOUT) ---
    ("U5", "Package_TO_SOT_SMD", "SOT-223-3_TabPin2",
     118, 12, 0, "AMS1117-3.3", {
        "1":"GND","2":"+3V3","3":"+5V",
     }),
    # --- WS2812 ring connector : 1x03 ---
    ("DS1", "Connector_PinHeader_2.54mm", "PinHeader_1x03_P2.54mm_Vertical",
     114, 35, 0, "WS2812-Ring", {
        "1":"+5V_LED","2":"GND","3":"LED_DIN",
     }),
    # --- Rotary encoder EC11 with switch ---
    ("SW1", "Rotary_Encoder", "RotaryEncoder_Alps_EC11E-Switch_Vertical_H20mm",
     52, 85, 0, "EC11", {
        "A":"ENC_A","B":"ENC_B","C":"GND","S1":"BTN_CENTER","S2":"GND","MP":"GND",
     }),
    # --- Mute slide switch SPDT ---
    ("SW2", "Button_Switch_THT", "SW_DIP_SPSTx01_Slide_9.78x4.72mm_W7.62mm_P2.54mm",
     75, 92, 0, "Mute-SPDT", {
        "1":"MUTE_SW","2":"GND",
     }),
    # --- Jack 3.5mm with switch detect (PJ-320E) ---
    ("J1", "Connector_Audio", "Jack_3.5mm_PJ320E_Horizontal",
     98, 90, 0, "Jack-3.5mm", {
        "T":"AUDIO_L","R1":"AUDIO_R","R2":"JACK_DET","S":"GND",
     }),
    # --- USB-C receptacle (power only) ---
    ("J2", "Connector_USB", "USB_C_Receptacle_Amphenol_12401610E4-2A",
     68, 14, 0, "USB-C", {
        # VBUS pads -> +5V ; GND + shield -> GND
        "A4":"+5V","B4":"+5V","A9":"+5V","B9":"+5V",
        "A1":"GND","A12":"GND","B1":"GND","B12":"GND","SH":"GND",
     }),
    # --- Discrete passives ---
    ("R1", "Resistor_SMD", "R_0603_1608Metric", 50, 60, 0, "10k",
        {"1":"BTN_CENTER","2":"+3V3"}),
    ("R2", "Resistor_SMD", "R_0603_1608Metric", 100, 33, 0, "330",
        {"1":"LED_DIN_RAW","2":"LED_DIN"}),
    ("C1", "Capacitor_SMD", "C_0603_1608Metric", 92, 10, 0, "10uF",
        {"1":"+5V","2":"GND"}),
    ("C2", "Capacitor_SMD", "C_0603_1608Metric", 97, 10, 0, "100nF",
        {"1":"+5V","2":"GND"}),
    ("C3", "Capacitor_SMD", "C_0603_1608Metric", 102, 10, 0, "10uF",
        {"1":"+3V3","2":"GND"}),
    ("C4", "Capacitor_SMD", "C_0603_1608Metric", 107, 10, 0, "10uF",
        {"1":"+3V3","2":"GND"}),
    ("C5", "Capacitor_SMD", "CP_Elec_5x5.3", 112, 90, 0, "100uF",
        {"1":"+5V","2":"GND"}),
    ("C6", "Capacitor_SMD", "CP_Elec_5x5.3", 139, 13, 0, "470uF",
        {"1":"+5V_LED","2":"GND"}),
    # --- P-MOSFET AO3401 SOT-23 (1=Gate 2=Source 3=Drain) : LED power gate ---
    ("Q1", "Package_TO_SOT_SMD", "SOT-23", 114, 54, 0, "AO3401",
        {"1":"LED_PWR_EN","2":"+5V","3":"+5V_LED"}),
    # --- P-MOSFET AO3401 SOT-23 : amp power gate (GPIO47 enables PAM8403) ---
    ("Q2", "Package_TO_SOT_SMD", "SOT-23", 95, 64, 0, "AO3401",
        {"1":"AMP_EN","2":"+5V","3":"+5V_AMP"}),
    # --- Ferrite bead ---
    ("F1", "Inductor_SMD", "L_0805_2012Metric", 131, 12, 0, "Ferrite 600R",
        {"1":"+5V","2":"+5V_LED"}),
    # --- Speaker connectors (BTL differential : connect across +/- , NOT to GND) ---
    ("HP1", "Connector_PinHeader_2.54mm", "PinHeader_1x02_P2.54mm_Vertical",
     124, 66, 0, "HP-Left", {"1":"SPK_L+","2":"SPK_L-"}),
    ("HP2", "Connector_PinHeader_2.54mm", "PinHeader_1x02_P2.54mm_Vertical",
     124, 80, 0, "HP-Right", {"1":"SPK_R+","2":"SPK_R-"}),
    # --- Trous de fixation M3 -> entretoises du boitier v4 -------------------
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

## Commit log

2026-06-11 Initial commit - s3-salle-de-bain v3
    [diffuser_ring.scad, diffuser_ring.stl, housing_body.scad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]
2026-06-11 feat(kicad): add KiCad 8 project (schematic + PCB outline + netlist)
    [s3-salle-de-bain.kicad_pcb, s3-salle-de-bain.kicad_sch]
2026-06-11 fix(kicad): properly wire schematic with 97 wires + 30 junctions, add SVG preview
    [s3-salle-de-bain.kicad_pcb, s3-salle-de-bain.kicad_sch]
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2026-06-11 feat(kicad): pre-populated PCB with 14 footprints + 23 nets connected
    [s3-salle-de-bain.kicad_pcb]
2026-06-11 chore(kicad): sync sch/pro/net after PCB rebuild
    [s3-salle-de-bain.kicad_sch]
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2026-06-12 feat(kicad): real KiCad standard symbols (Device:R, Device:C, power:GND, Q_PMOS_GSD, Speaker, SW_SPDT)
    [s3-salle-de-bain.kicad_sch]
2026-06-12 fix(kicad): real standard symbols (R/C/L/Q_PMOS/Speaker/power) + clean wiring
    - Extract exact symbols from KiCad 10 libs (no lib_symbol_mismatch)
    - Parse real pin positions (no off-grid, no unconnected endpoints)
    - Grid-snapped placement, PWR_FLAG on each rail
    - ERC: 216 -> 19 warnings (only cosmetic Local-lib notices)
    - Verified with kicad-cli erc/pdf/svg export
    - Official netlist: 24 nets, 22 components all connected
    [s3-salle-de-bain.kicad_sch]
2026-06-13 fix(pcb): real component footprints via pcbnew API (DRC clean)
    - 22 real footprints from KiCad libs (SOT-223, SOT-23, EC11 encoder,
    PJ-320E jack, USB-C receptacle, SMD 0603/electrolytic, pin headers)
    - 99 pads assigned to 23 nets, ratsnest ready to route
    - DRC: 0 errors (edge clearance relaxed to 0.25mm for USB-C edge connector)
    - Schematic symbols carry matching Footprint property (sch<->pcb linked)
    - Verified with kicad-cli pcb drc + export
    [s3-salle-de-bain.kicad_pcb, s3-salle-de-bain.kicad_sch]
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2026-06-13 fix(pcb): real ESP32-S3-DevKitC footprint (official Espressif)
    - Download official Espressif ESP32-S3-DevKitC.kicad_mod (44 pads, 2x22)
    - Map nets to exact GPIO pads per Espressif silk pinout
    - Register Espressif.pretty in fp-lib-table
    - Reposition all components around the larger module footprint
    - DRC: 0 errors
    - Schematic U1 footprint property -> Espressif:ESP32-S3-DevKitC
    [s3-salle-de-bain.kicad_pcb, s3-salle-de-bain.kicad_sch]
2026-06-14 fix(pcb): real GY-PCM5102 module footprint (1x11 header + L/G/R)
    - Custom footprint matching the WCMCU/GY-PCM5102 board (31.8x23.8mm)
    - Pin order XMT FMT LCK DIN BCK SCL DMP FLT GND 3V3 VCC + L/G/R line-out
    - Net mapping per module silk (SCL/DMP/FLT/FMT->GND, XMT->3V3)
    - Schematic U2 symbol + footprint property updated to match
    - Register Modules.pretty in fp-lib-table
    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
    [s3-salle-de-bain.kicad_pcb, s3-salle-de-bain.kicad_sch]
2026-06-14 fix(pcb): real INMP441 + PAM8403 module footprints (from photos)
    - GY-INMP441 round footprint (2x3: L/R WS SCK / SD VDD GND)
    - PAM8403-mini footprint (BTL out L-/L+/R-/R+, audio in L/G/R, power +/-)
    - Speakers now wired differential (SPK_L+/L-, SPK_R+/R-) not to GND
    - Add Q2 P-MOSFET amp power-gate (GPIO47 enables PAM8403, no SHDN on module)
    - New +5V_AMP gated rail
    - Schematic symbols + footprint properties updated to match
    - Board widened to 145x108mm, DRC: 0 errors
    [s3-salle-de-bain.kicad_pcb, s3-salle-de-bain.kicad_sch]
2026-06-16 feat(cad): boitier v4 "galet" adapte a la carte 145x108 + 4 trous M3 PCB
    Boitier 3D imprime entierement redessine pour s'adapter a la carte
    porteuse KiCad (l'ancien cylindre Ø110 ne convenait pas).
    Boitier (cad/boitier_v4/):
    - galet rectangulaire arrondi (R28), design classe & epure
    - 2 HP 40mm front-firing (grilles hexagonales + anneaux M2.5)
    - molette centree : encodeur EC11 monte panneau (douille M7) +
    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
    [boitier_v4.3mf, params.scad, s3-salle-de-bain.kicad_pcb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]
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2026-06-16 feat(cad): export STEP (B-rep) des pieces du boitier v4
    OpenSCAD n'exporte pas le STEP (maillage, pas de B-rep) : les .step sont
    des solides B-rep facettes reconstruits depuis les STL via FreeCAD
    (stl_to_step.py, couture fine 1e-5 pour preserver les grilles hexagonales).
    - v4_base.step : valide, ferme, 1 solide, ~107 cm3 (~22 Mo, grilles hex)
    - v4_top.step : valide, ferme, 1 solide
    - v4_speaker_gasket.step : valide, 2 solides
    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
    [v4_speaker_gasket.step, v4_top.step]
2026-06-16 feat(cad): re-adapte le boitier v4 a la carte modifiee 76.7 x 108 mm
    La carte a ete refondue (145x108 -> 76.7x108, export JLCPCB). Boitier relu
    et recale sur l'implantation REELLE (kicad/dump_pcb_geo.py) :
    - encombrement 158x121x53 -> 121x90x57 mm (galet compact)
    - entretoises PCB alignees sur les 4 trous reels MK1-MK4 de la carte
    - USB-C decale sur le connecteur J2 reel (paroi arriere -Y)
    - micro pinhole place au-dessus du module INMP441
    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
    [boitier_v4.3mf, params.scad, v4_base.scad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]
2026-06-16 fix(cad): STEP du bac valide et leger (23 Mo -> 2,5 Mo)
    Cause de l'invalidite OCCT identifiee : l'alesage de l'anneau de vissage HP
    etait exactement egal a l'ouverture de grille (Ø33) -> surfaces cylindriques
    coincidentes -> auto-intersections du maillage. Corrige (alesage Ø34.6).
    - bac STEP : ouvertures HP circulaires + $fn reduit -> solide VALIDE, ferme,
    2,5 Mo (au lieu de 23 Mo facettes invalides)
    - grilles hexagonales conservees dans le STL d'impression / .scad (flag
    grille_simple) ; STEP = reference CAO
    - base_simple_to_step.py : convertisseur dedie du bac
    [boitier_v4.3mf, params.scad, v4_base.scad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]
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2026-06-16 docs: maj rapport technique (boitier v4 + carte 76.7x108)
    Sections 10 (Boitier 3D), 11 (Vue eclatee/nomenclature) et bloc CAO
    reecrites pour refleter tous les changements :
    - galet rectangulaire 121x90x57 mm en PA-CF (au lieu du cylindre ABS Ø110)
    - carte porteuse 76,7 x 108 mm, 4 entretoises M3 sur trous MK1-MK4 reels
    - 2 HP 40 mm front-firing, molette EC11 centrale, fermeture press-fit
    - fichiers CAO : v4_base / v4_top / v4_speaker_gasket (STL + STEP + .3mf)
    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
2026-06-16 docs: maj rapport technique PDF (boitier v4 + carte 76.7x108)
    Meme mise a jour que le DOCX, cote PDF (ReportLab) :
    - galet PA-CF 121x90x57 (au lieu du cylindre ABS Ø110)
    - carte 76,7x108, entretoises sur trous MK1-MK4, USB-C sur J2
    - 2 HP front-firing, molette EC11, fermeture press-fit
    - CAO : v4_base/v4_top/v4_speaker_gasket (STL + STEP + .3mf)
    - figures 4 et 5 = rendus CAO du galet v4
    - chemin assets corrige (esp32_assets deplace)
    [s3-salle-de-bain.GBL, s3-salle-de-bain.GBO, s3-salle-de-bain.GBP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]
2026-06-16 feat(cad): grave le logo DOMOKAMI + version sous le bac
    Marquage discret sous le bac (top epure preserve), lisible boitier
    retourne (texte miroir). Wordmark texte "DOMOKAMI" + "S3 v4", grave 0.6 mm,
    a l'ecart des events et des pieds. Tout parametrable (brand_* dans params.scad).
    STL + STEP (valide, 2583 faces) + .3mf regeneres.
    [boitier_v4.3mf, params.scad, v4_base.scad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]
2026-06-16 feat(cad): marquage DOMOKAMI + version EN RELIEF sur le capot
    Deplace le marquage du dessous (grave) vers le capot (en relief), sous la
    molette, cote facade -> lisible face a l'utilisateur (meme cote que les HP).
    - relief 0.6 mm, texte oriente pour lecture depuis l'avant (+Y)
    - bac : gravure du dessous retiree -> STEP de nouveau a 2,5 Mo
    - capot : STEP valide (4579 faces, 7 Mo, lettres en relief)
    - STL + STEP + .3mf + apercus regeneres ; ajout vue de face, retrait vue dessous
    [boitier_v4.3mf, params.scad, v4_base.scad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]
2026-06-16 docs: figures des rapports avec le marquage DOMOKAMI en relief
    Fig. 4 (vue de face) et Fig. 5 (eclate) regenerees -> le logo DOMOKAMI +
    version S3 v4 en relief sur le capot est desormais visible dans le DOCX et le PDF.
2026-06-17 feat(cad): boitier v5 "galet integral" - 4 HP + basses (radiateurs passifs)
    Refonte demandee : forme galet tres arrondie (toutes aretes adoucies,
    fillet 12 / coins R36) et 4 HP dont 2 radiateurs passifs pour les basses.
    - 2 HP plein-bande actifs en facade (+Y) + 2 radiateurs passifs arriere (-Y)
    - caisson ETANCHE (events supprimes) ; 4 joints TPU fournis
    - PCB inchange (radiateurs passifs = aucun cablage) ; USB-C en bas, sous
    les radiateurs (degagement vertical), aligne sur J2 reel
    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
    [boitier_v5.3mf, params.scad, v5_assembly.scad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]
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2026-06-17 fix(cad): boitier v5 agrandi (trous PCB a l'interieur) + grilles HP propres
    - pcb_clear 4 -> 8 : boitier agrandi a 129 x 98 x 69 mm ; les entretoises /
    trous MK1-MK4 sont maintenant bien DANS la cavite (plus de fragment :
    bac = 1 solide propre, Volumes 2)
    - grilles HP : uniquement des hexagones ENTIERS (plus de demi-hexagones ni
    slivers au bord) -> "polygones manquants" cote HP corriges
    - STL + STEP (valides) + .3mf regeneres
    - rapports DOCX + PDF : cotes 129 x 98 mises a jour
    [boitier_v5.3mf, params.scad, v5_speaker_gasket.step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]
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2026-06-17 feat(cad): boitier v6 style JBL - radiateurs aux bouts, USB-C degage
    Refonte style JBL Go/Clip (plat & large) + correction du chevauchement
    USB-C / HP de la v5 :
    - 2 HP actifs en facade (2 grilles rondes) + 2 RADIATEURS PASSIFS sur les
    2 BOUTS (+-X) avec logo DOMOKAMI en relief (facon logo JBL sur la membrane)
    - USB-C SEUL a l'arriere -> plus aucun chevauchement avec un HP
    - format 129 x 98 x 58 mm (plat), coins R24, aretes R7, carte 76,7 x 108
    - caisson etanche, 4 joints TPU ; PCB inchange (radiateurs passifs)
    - STL (1 solide) + STEP valides + .3mf
    - rapport PDF mis a jour en v6 + image PCB ajoutee (Fig. 2, apres le schema)
    - cad/README.txt pointe la v6 ; v4 et v5 conservees
    Co-Authored-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
    [boitier_v6.3mf, params.scad, v6_assembly.scad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]
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2026-06-30 feat: ampli externe 4 voies (LOTHYE) -> 4 HP ACTIFS
    L'utilisateur passe a un ampli 4 voies (2x PAM8403). Le PAM8403 est 2 voies :
    la carte "4 voies" = 2x PAM8403. Source stereo dupliquee sur 4 HP actifs.
    PCB:
    - retire le PAM8403 soude (U3) + les 2 connecteurs HP embarques
    - ajoute J3 (alim 5V de l'ampli externe, gated par Q2/GPIO47)
    - l'audio sort par le jack 3.5mm J1 (deja cable AUDIO_L/R) -> entree ampli
    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
    [s3-salle-de-bain.kicad_pcb]
2026-06-30 revert: retour a l'ancien PCB (PAM8403 soude 2 voies)
    Annule la refonte ampli 4 voies (commit 6156e1e) : restaure le PAM8403
    soude U3 + connecteurs HP1/HP2, retire J3. Docs (DOCX/PDF) revenues a la
    version v6 coherente (2 HP actifs + 2 radiateurs passifs). Fichiers
    restaures depuis ac44fe8.
    [s3-salle-de-bain.kicad_pcb]
